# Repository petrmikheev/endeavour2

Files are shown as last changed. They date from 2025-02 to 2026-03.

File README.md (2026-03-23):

Endeavour2
==========

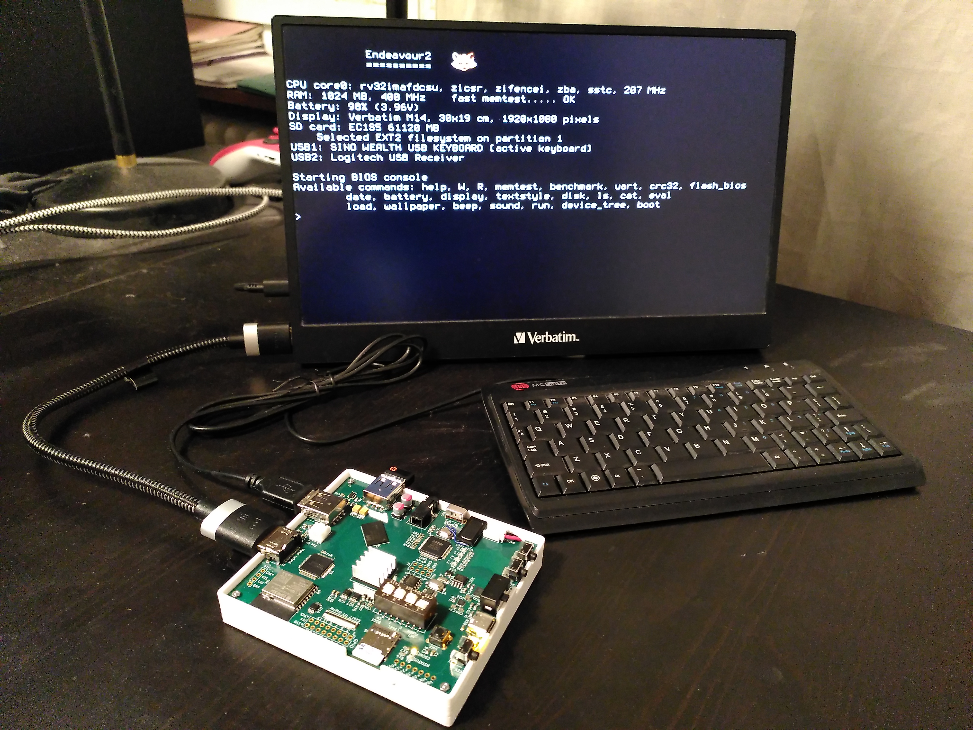
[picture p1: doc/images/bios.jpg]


This is the second generation of my FPGA board.
Comparing to [endeavour1](https://github.com/petrmikheev/endeavour) it is 4 times faster and has 8x more memory.

The goal was the same as on the previous iteration -- to make a DIY computer based on FPGA. It should support display, keyboard, should be able to run Linux, should have on-device compiler toolchain, and ideally should be able to render some 3D graphic. It was fully achieved -- I have even managed to connect my board to WiFi and play Quake2 in multiplayer.

The project includes several parts:

- Hardware: design PCB and make the board. I ordered PCB manufacturing in JLCPCB, soldering is done manually.
- RTL: design SoC for my FPGA board. It is mostly assembled from open source IP cores, but some components are implemented from scratch.
- Firmware: written from scratch (except of integrated Dhrystone benchmark), includes initialization code, memtest, sbi implemetation, ext2 filesystem support, linux bootloader, built-in console. Provides some API (e.g printf) for software running in M-mode.
- Linux drivers for custom peripherals.
- Custom window manager and TTY implementation.

Note: This is a hobby project created just for fun. It doesn't have much practical use. However, if for some reason somebody wants to make a copy of this FPGA board, please let me know. I might add a bit more documentation.

Here's a story about how I worked on the project: **[https://blog.mikhe.ch/quake2-on-fpga](https://blog.mikhe.ch/quake2-on-fpga)**.

License: GPL-3.0 (except of footprints in hardware/endeavour2.pretty and Dhrystone benchmark in software/bios/dhrystone)

## Hardware

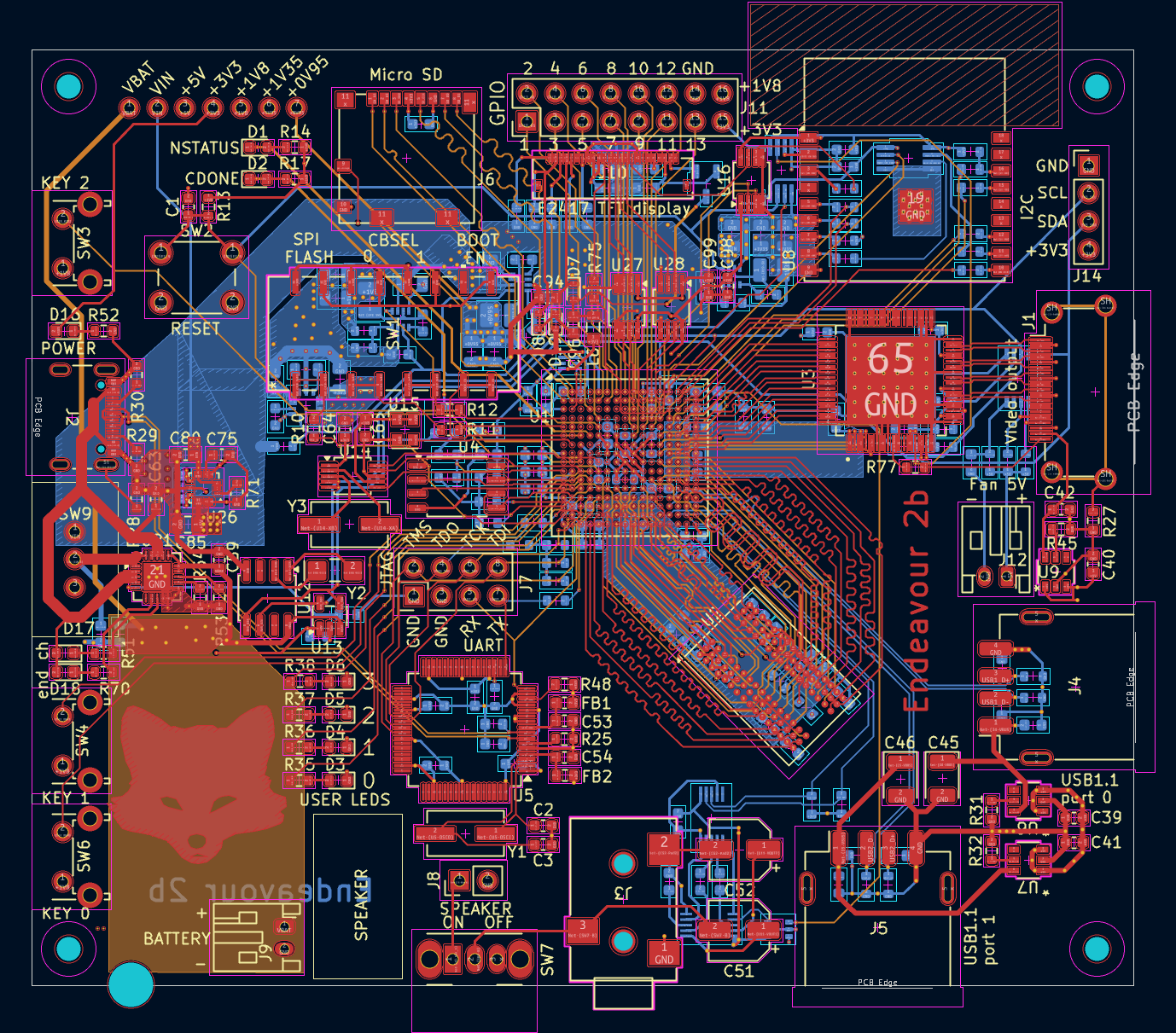
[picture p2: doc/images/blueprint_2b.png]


Main changes comparing to [endeavour1](https://github.com/petrmikheev/endeavour):

- This time I took a chance with BGA (Ball Grid Array) chips, and surprisingly soldering was not as hard as I expected.
- Using Efinix FPGA [Ti60F256](https://www.efinixinc.com/shop/ti60.php) with 60K logic cells and 256 1024x10b memory blocks. VexiiRiscv runs on this chip at frequency 207 MHz -- quite a lot for FPGA, especially in comparison to 60 MHz which I previously got with Altera Max10.
- 1GB DDR3 RAM IM8G16D3FFBG (against 128MB DDR1 in endeavour1). I use Efinix DDR3 Soft Controller Core. Using DDR3-400 mode, 800 MT/s, max theoretical throughput 1.6 GB/s. In practice in benchmarks I get up to 1.1 GB/s.
- Implemented SD Card voltage switch 3.3V/1.8V. In theory it allows to use UHS-1 cards in SDR104 mode (up to 100 MB/s), but for some cards writes failed at this speed, so I use SDR50 (46 MB/s in benchmark).
- Added a specialized TMDS encoder TFP410 (in endeavour1 video output was driven directly by FPGA pins which provided not enough current and caused green artifacts in some cases). Now all display modes with pixel rate up to 165 MHz are supported.
- More capacitors and a current limiting scheme on USB ports. USB hotplug can not cause device reset anymore!
- Added a real time clock in order not to appear in 1970 every time I start linux.
- Added ESP32 module as a WiFi adapter. `wget` shows download speed 926 KB/s.
- Added 2000mAh LiPo battery. 
- Added 4.2'' E-Ink display.

[KiCad project](hardware/board_2b), [gerber files](hardware/board_2b/production/endeavour2.zip).

**PCB production details ([JLCPCB](https://jlcpcb.com/capabilities/pcb-capabilities))**

- 6 layers
- Stackup: JLC06161H-3313
- Min via hole/diameter: 0.2/0.35mm
- Via covering: epoxy filled & capped

---



Endeavour2a (above) and Endeavour2b (below).

### Known design errors

In Endeavour2a:

- D+ and D- lines on USB-C port A are accidentally swapped, so port A can be used only as a power source. There are two USB-C ports because I was not sure that USB connection to PC will give enough power, and added a second USB-C for a power adapter. It turned out to be unnecessary, so in Endeavour2b the second port is removed.
- ESP32 connection scheme includes not all the pins which are needed for [ESP-Hosted-NG](https://github.com/espressif/esp-hosted/blob/master/esp_hosted_ng/README.md) firmware. I tried to remap some pins, but it caused extra delays and SPI transfers didn't work properly. So Endeavour2a has no WiFi. Fixed in Endeavour2b.

In Endeavour2b:

- Using same DC-DC converters as in Endeavour2a (TPS562211) to generate 0.95V, 1.35V, 1.8V. I forgot that it requires input power at least 4.2V and can work from USB (which was the case in Endeavour2a), but not from a battery pack. So the device can use battery power only when the battery is fully charged. Will be fixed in Endeavour2c.

### 3d printed case

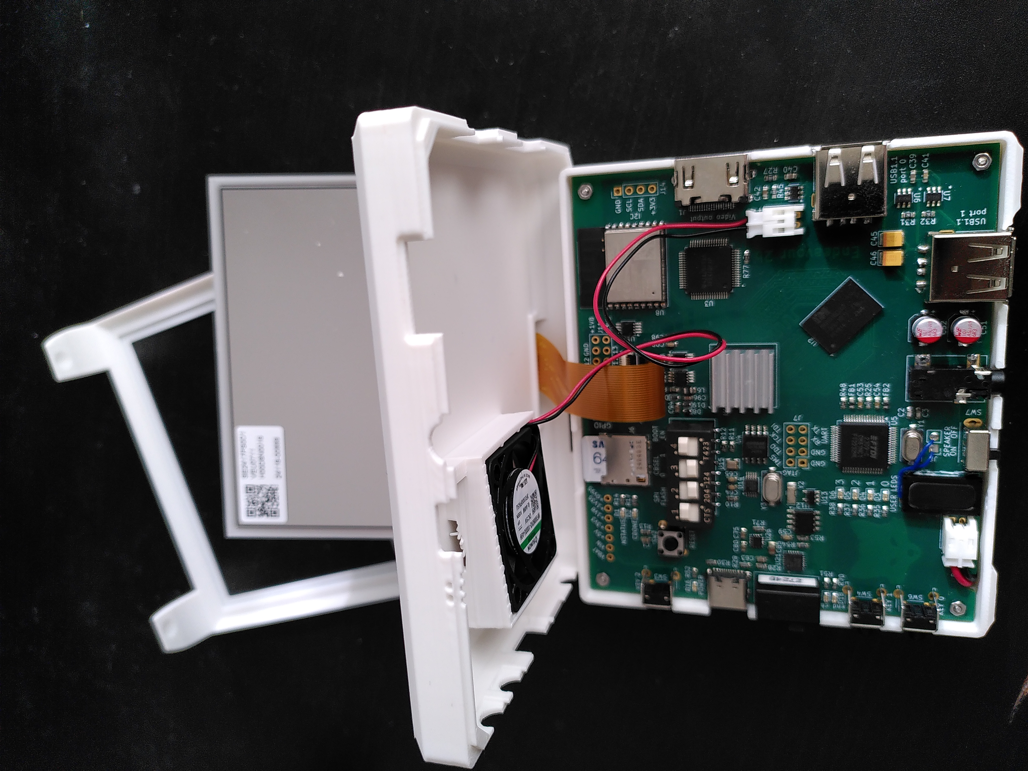
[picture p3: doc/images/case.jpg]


---



## RTL

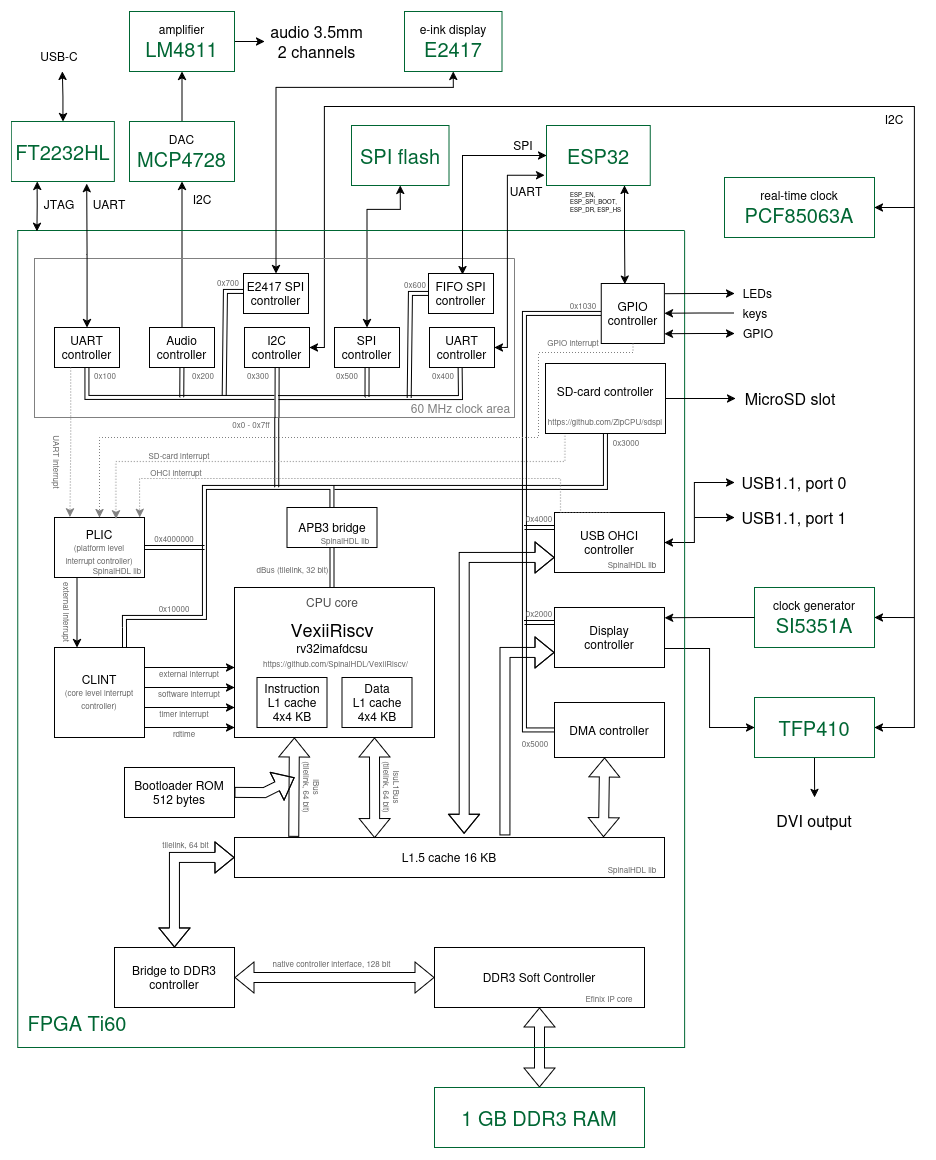
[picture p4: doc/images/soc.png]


Used IP cores:

- [VexiiRiscv](https://github.com/SpinalHDL/VexiiRiscv/) - RISC-V core written in SpinalHDL.
- A few components distributed with [SpinalHDL](https://github.com/SpinalHDL/SpinalHDL) including Tilelink interconnect, APB3 bridge, USB OHCI controller, PLIC.
- [ZipCPU/sdspi SD-Card controller](https://github.com/ZipCPU/sdspi).
- [Efinix DDR3 Soft Controller Core](https://www.efinixinc.com/support/ip/ddr3-controller.php) (source not available, can be used only with Efinix FPGAs).

All the other components are designed from scratch.
DDR3 Tilelink adapter, UART controller, I2C controller, audio controller, SPI controllers (SPI FLASH, ESP32 SPI, and E2417 SPI interfaces have different requirements, so I end up with 3 different SPI controllers optimized for specific use cases), etc. Most notable are video controller and DMA controller.

[SpinalHDL](https://github.com/SpinalHDL/SpinalHDL) is being used to bring this all together.

### Video controller

- Has idependent text and graphic layers with transparency support.
- Configurable video timings.
- Supports both vertical (with wraparound) and horizontal panning.
- Graphic layer uses RGB565 format.
- Text layer has configurable charmap with 480 entries - e.g. ASCII + bold + italic variations + pseudographics can be loaded at the same time. Supports bitmap fonts with sizes from 8x8 to 8x16. Supports special 4-color symbols mode (used to render Endeavour logo, see screenshots below).
- APB3 control interface, Tilelink DMA interface.
- Implemented in verilog. [source](rtl/verilog/video_controller.v)
- There is [linux driver](software/linux/drivers/display.c). See usage in [include/endeavour2/display.h](software/include/endeavour2/display.h).

### DMA controller

- Can execute multiple memory operations by a single batch request from CPU (needed e.g. for hardware-accelerated window move in X11 since each line requires separate copying).
- Supports unaligned memset and memcpy (also essential for window move).
- Supports some graphics-related instructions: batched RGB565 mixing and palette mapping. So it is kind of a very primitive 2D GPU. I used it to speedup rendering in Quake2.
- APB3 control interface, Tilelink DMA interface.
- Implemented in SpinalHDL. [source](rtl/src/main/scala/endeavour2/DmaController.scala)

## Software

### [software/bios](software/bios)

Firmware. Initialization, benchmarks, sbi, bootloader, etc. Loaded on boot from SPI flash or via UART.

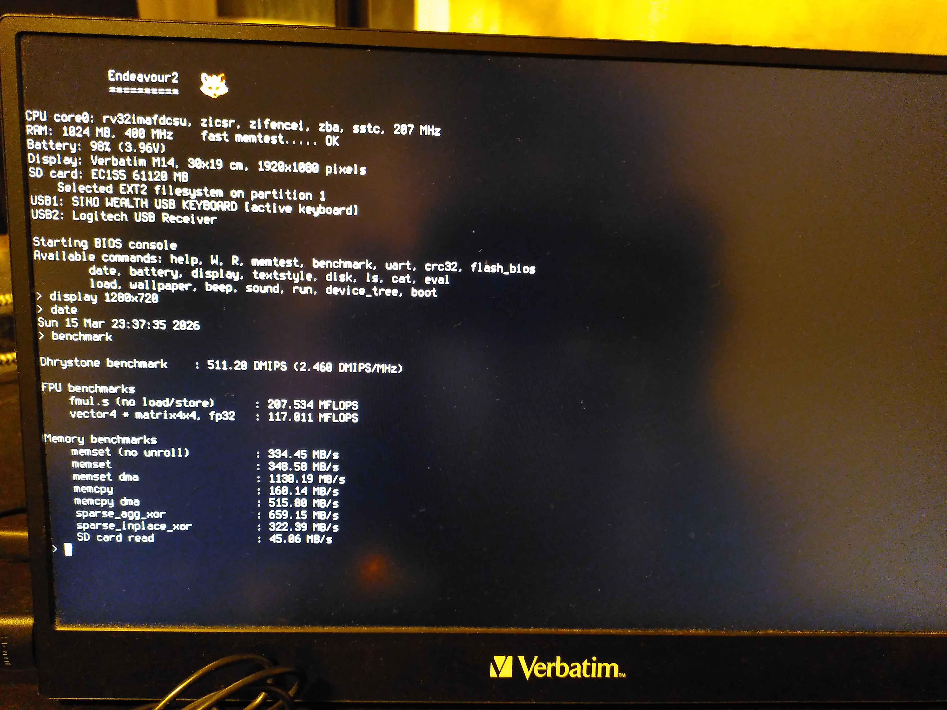
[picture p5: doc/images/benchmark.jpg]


BIOS console allows to either boot OS (switches to supervisor mode), or inspect files (only EXT2 supported) and run binaries in machine mode.

BIOS provides API: [bios.h](software/include/endeavour2/raw/bios.h)

Example that uses this API: [hello_world.c](software/raw_examples/hello_world.c)

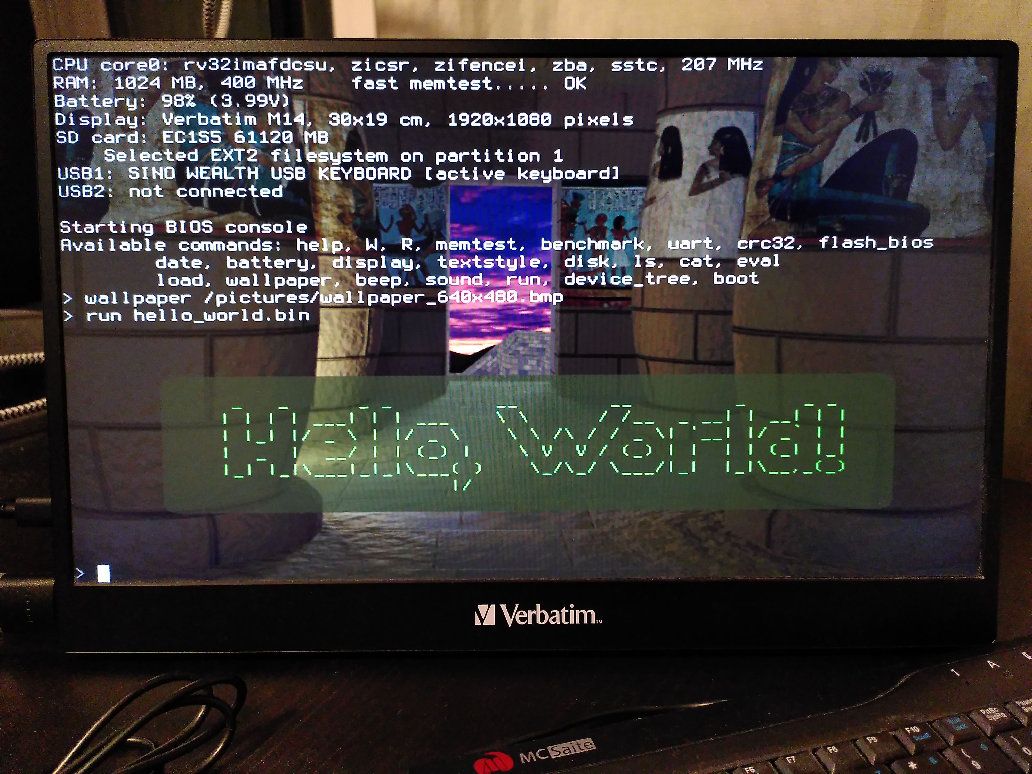
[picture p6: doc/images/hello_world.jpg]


### [software/textwm2](software/textwm2)

Text-layer window manager and TTY implementation.

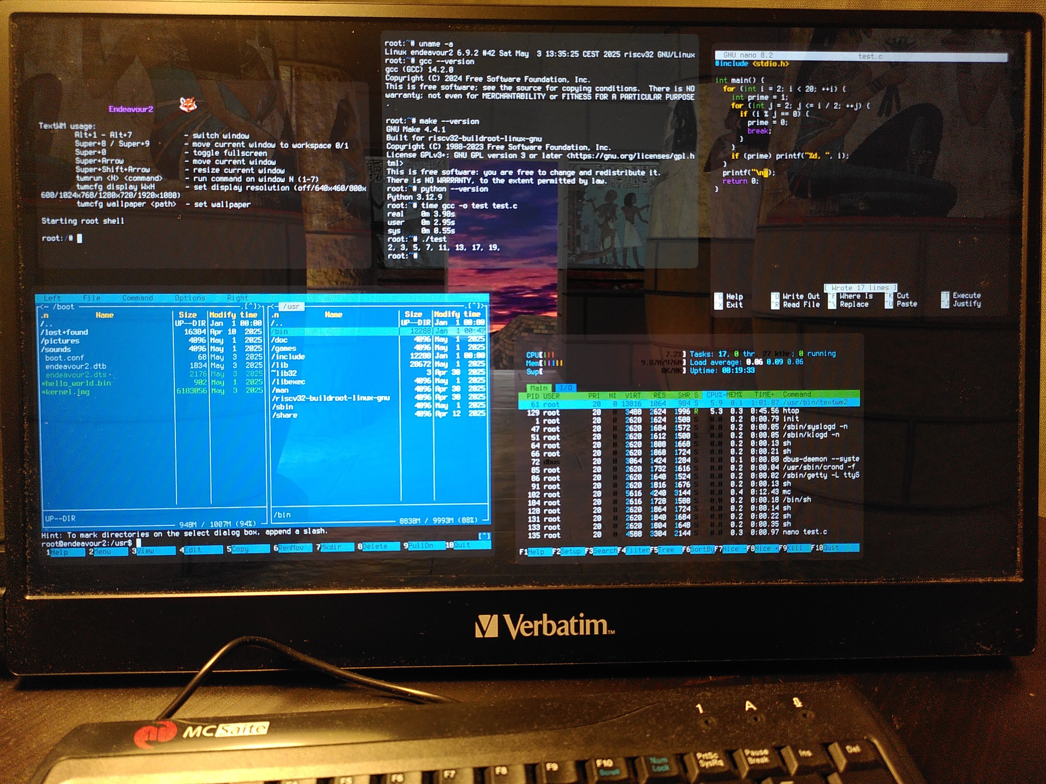
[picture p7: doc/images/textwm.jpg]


---

**wget 926 KB/s**, ESP32 as WiFi/BT adapter.



### [software/linux](software/linux)

Linux kernel config and drivers.

### [software/buildroot](software/buildroot)

Buildroot config and a few related scripts.

### [xdriver-endeavour2-fbdev](software/buildroot/xdriver-endeavour2-fbdev)

X11 driver which uses DMA controller when moving windows.

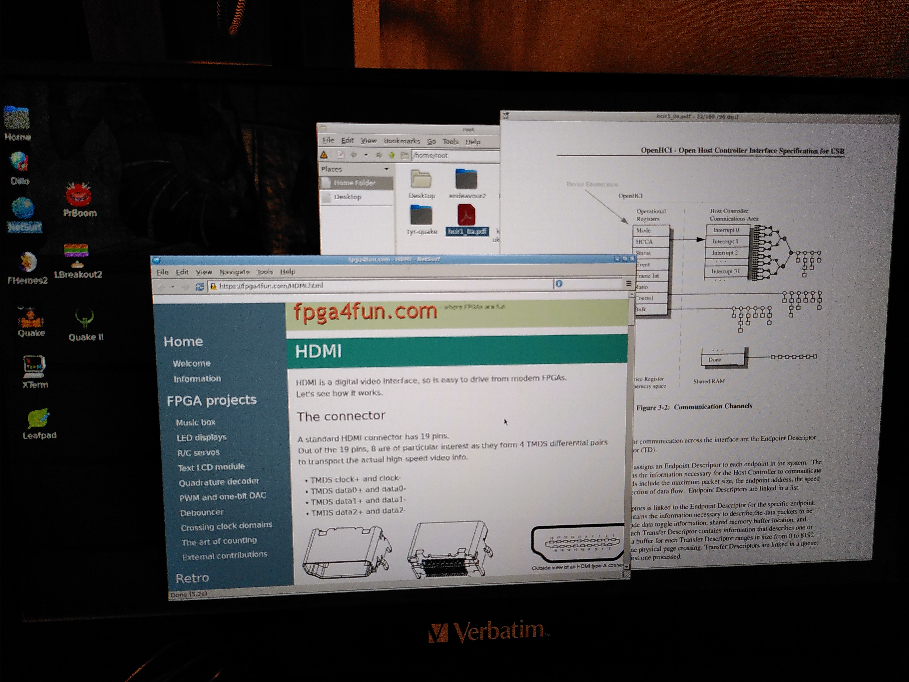
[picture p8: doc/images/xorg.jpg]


### [quake2sdl.patch](software/buildroot/quake2sdl.patch)



Patch for [quake2sdl](https://github.com/shamazmazum/quake2sdl).

- Using DMA controller for hardware-accelerated mapping from 256 colors to RGB565, and bilinear upscaling.
- Migrated from SDL audio to a custom endeavour2 driver with lower overhead (overhead of ALSA subsystem was quite significant).
- Downgraded from SDL2 to SDL1 (so it can run without X11).

Average FPS 12.2 on demo1 map with resolution 640x360 and bilinear upscaling to 1280x720.

### A few more screenshots

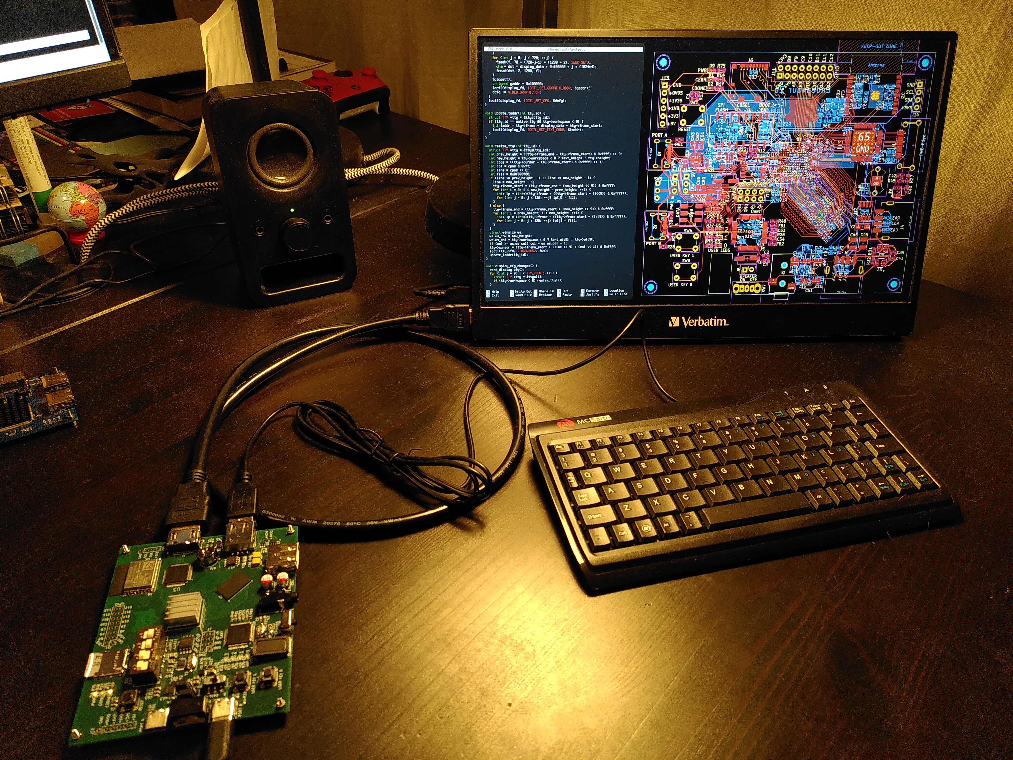
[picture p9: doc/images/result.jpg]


---

**DOOM**

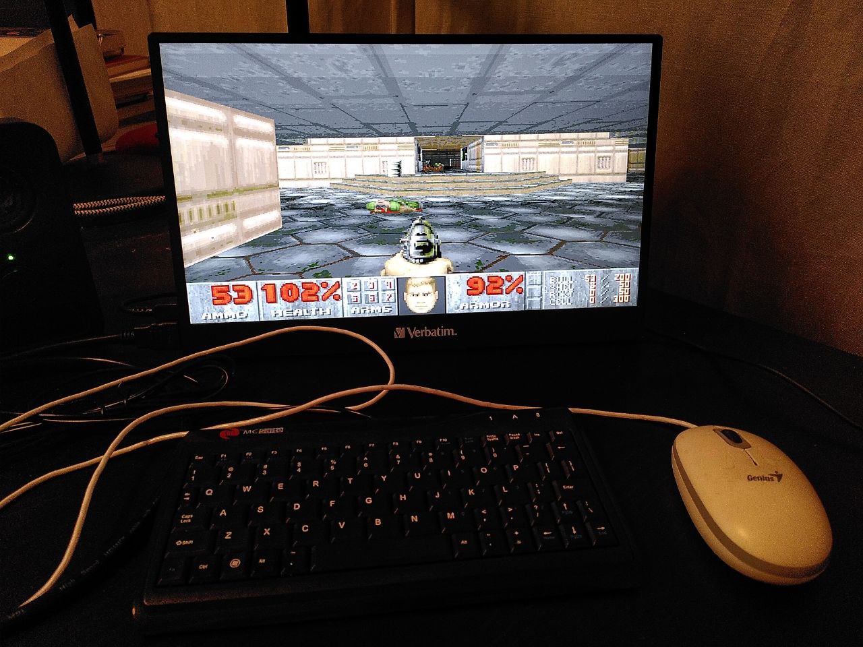
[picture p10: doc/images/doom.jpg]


---

**Quake 1**



---

**Heroes2**

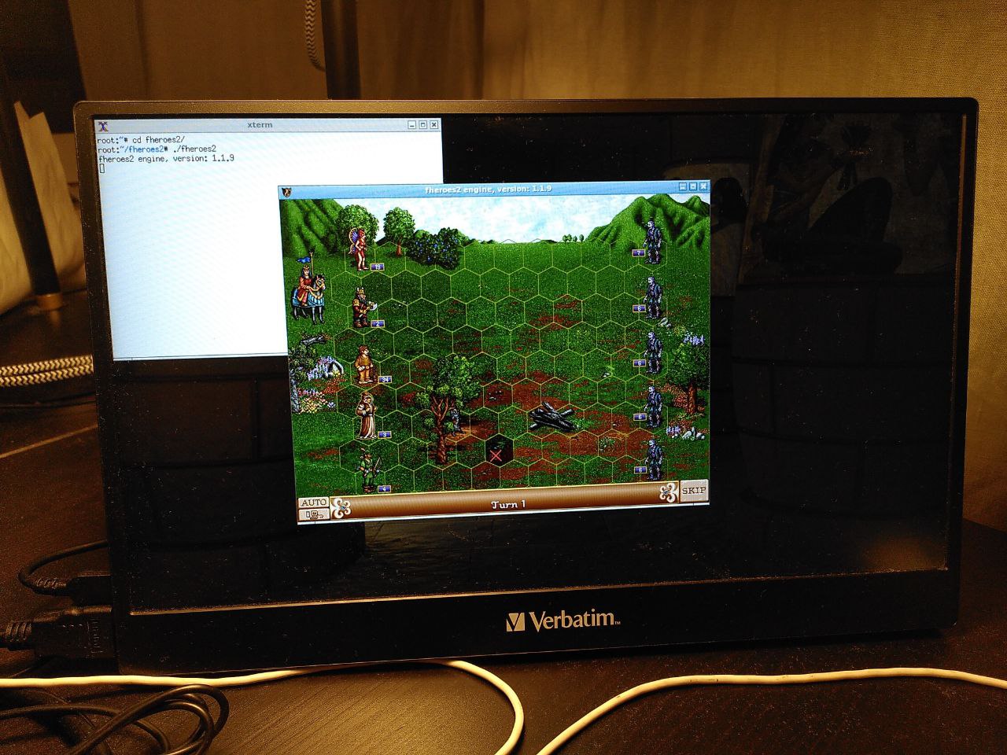
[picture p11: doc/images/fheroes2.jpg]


---

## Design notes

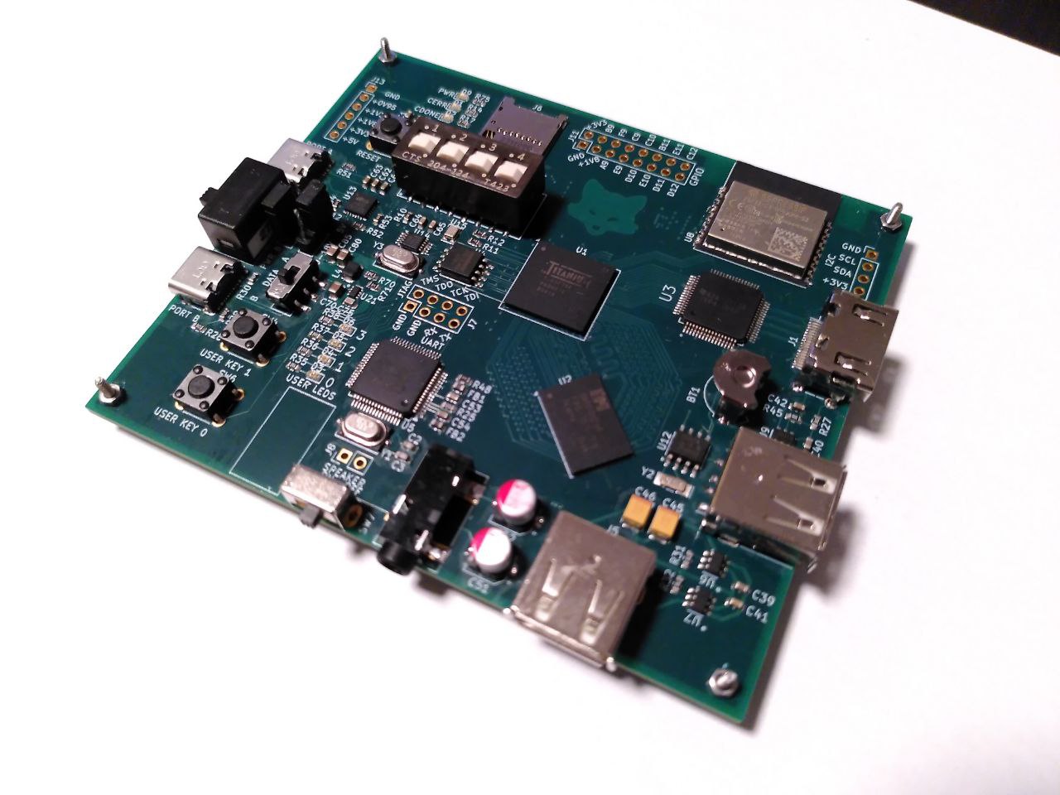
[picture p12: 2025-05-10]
doc/images/board_2a.jpg

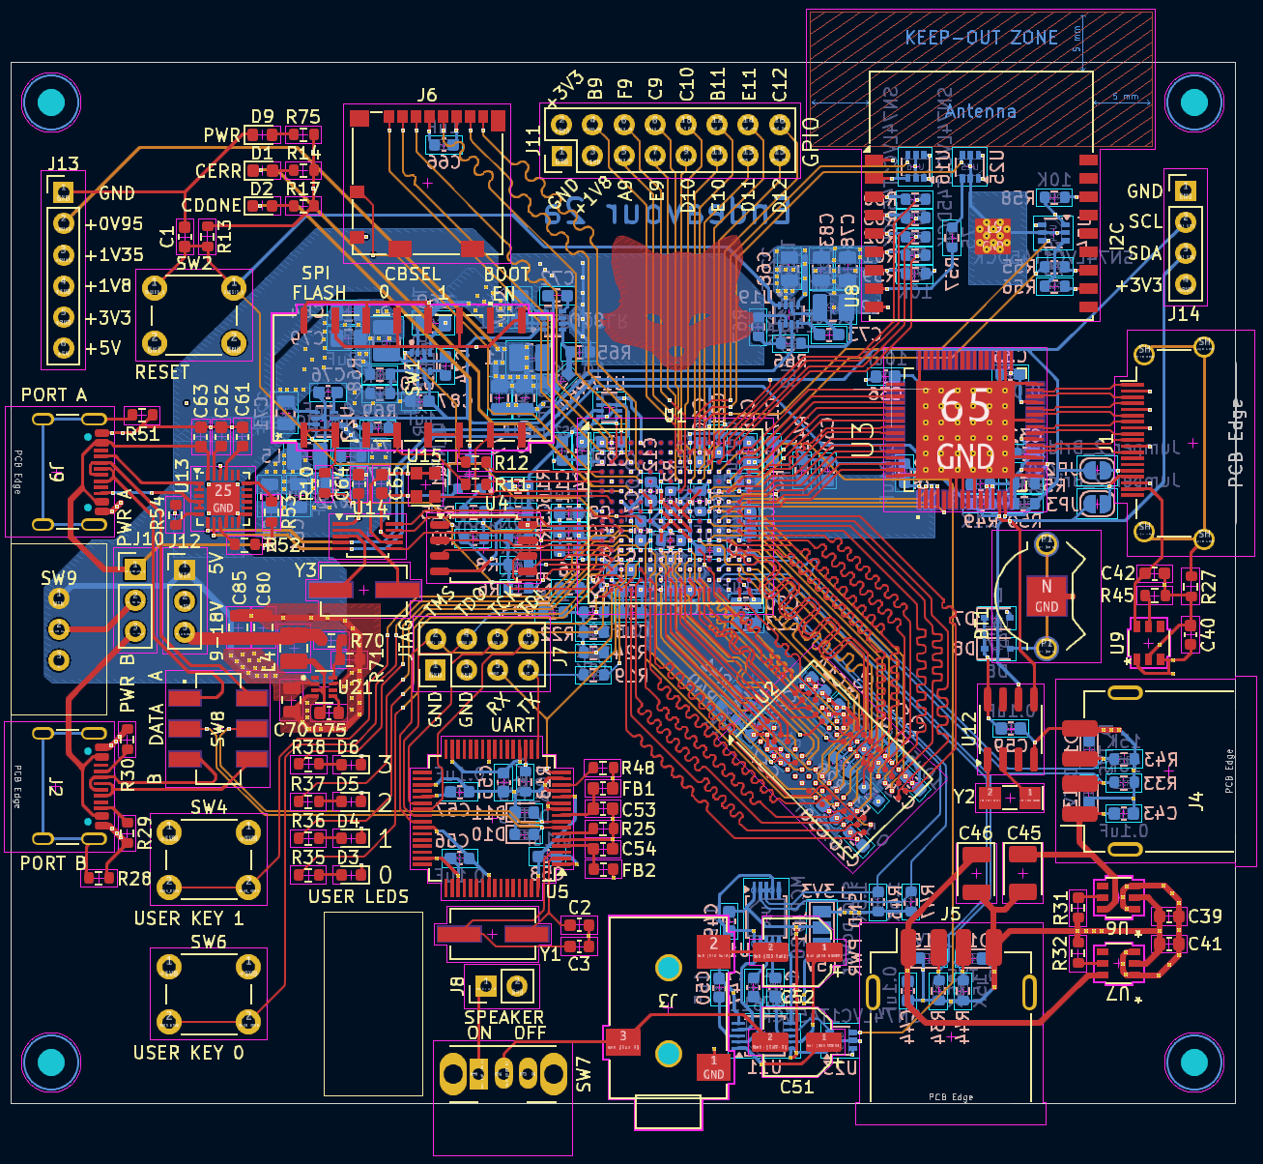
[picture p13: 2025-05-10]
doc/images/blueprint_2a.png

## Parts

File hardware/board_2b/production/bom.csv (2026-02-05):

Designator | Footprint | Quantity | Value | LCSC Part #
 |  | 1
C1, C14, C17, C4, C47, C48, C49, C50, C53, C54, C66, C75, C76, C87, C9, C91 | 0603 | 16 | 1uF
C10, C13, C24, C36, C39, C40, C42, C63, C71, C80 | 0603 | 10 | 10uF
C100, C101, C19, C20, C21, C22, C25, C26, C29, C30, C31, C41, C43, C44, C5, C55, C56, C57, C58, C59, C60, C64, C65, C70, C72, C73, C74, C93, C97, C98, C99 | 0603 | 31 | 0.1uF
C11, C23, C28, C61, C62, C8, C86, C88, C89, C90, C92, C94, C95, C96 | 0603 | 14 | 4.7uF
C12, C15, C18, C27, C32, C33, C34, C35, C37, C38, C7 | 0603 | 11 | 0.01uF
C16, C6 | 0603 | 2 | 47uF
C2, C3 | 0603 | 2 | 27pF
C45, C46 | CP_EIA-3528-12_Kemet-T | 2 | 100uF
C51, C52 | CP_Elec_5x5.3 | 2 | 100uF
C67, C68, C69, C77, C78, C79, C81, C82, C83, C84, C85 | 0805 | 11 | 22uF
D1, D17 | 0603 | 2 | 5988E20107F
D10, D11, D12, D13, D14, D15 | 0603 | 6 | D_TVS 3v3
D16, D18, D2, D3, D4, D5, D6 | 0603 | 7 | 5988E40107F
D19, D7, D8 | D_SOD-523 | 3 | RB751S40T1G
FB1, FB2 | 0603 | 2 | 120
J1 | HDMI_A_Amphenol_10029449-x01xLF_Horizontal | 1 | HDMI_A
J10 | CONN24X1_CF35242D0RE-NH_CVI | 1 | CF35242D0RE-NH
J11 | PinHeader_2x08_P2.54mm_Vertical | 1 | Conn_GPIO
J12 | JST_PH_S2B-PH-K_1x02_P2.00mm_Horizontal | 1 | Fan
J13 | PinHeader_1x07_P2.54mm_Vertical | 1 | power_test_points
J14 | PinHeader_1x04_P2.54mm_Vertical | 1 | Conn_01x04_Pin
J2 | USB_C_Receptacle_GCT_USB4105-xx-A_16P_TopMnt_Horizontal | 1 | USB_C_Receptacle_USB2.0
J3 | SJ-3523-SMT_CUD | 1 | SJ-3523-SMT
J4, J5 | USB_A_Receptacle_GCT_USB1046 | 2 | USB_A
J6 | microSD_HC_Molex_104031-0811 | 1 | Micro_SD_Card_Det2
J7 | PinHeader_2x04_P2.54mm_Vertical | 1 | Conn_02x04_Odd_Even
J8 | PinHeader_1x02_P2.54mm_Vertical | 1 | Conn_01x02
J9 | JST_PH_S2B-PH-K_1x02_P2.00mm_Horizontal | 1 | Battery
L1, L2, L3 | 1008 | 3 | 2.2uH
L4, L5 | 0805 | 2 | 1uH
L6 | 0805 | 1 | 10uH
Q1 | SC-59 | 1 | Q_NPN_BEC 2SC3326-B,LF
Q2 | SOT-23-3 | 1 | SSM3K336R,LF
R1 | 0603 | 1 | 240
R10, R11, R12, R13, R16, R18, R2, R21, R22, R23, R24, R3, R4, R58, R59, R6, R7, R74, R8, R9, TH1 | 0603 | 21 | 10K
R14, R17, R35, R36, R37, R38 | 0603 | 6 | 25
R15 | 0603 | 1 | 100K
R19, R20, R55, R56, R57, R60, R61, R62, R63, R73, R75, R76 | 0603 | 12 | 75
R25 | 0603 | 1 | 12K
R26 | 0603 | 1 | 100
R27, R28 | 0603 | 2 | 1M
R29, R30, R49, R50 | 0603 | 4 | 5.1K
R31, R32 | 0603 | 2 | 60K
R33, R34, R43, R44, R54 | 0603 | 5 | 15K
R39, R40, R41, R42, R48, R77 | 0603 | 6 | 1K
R45, R78 | 0603 | 2 | 200K
R46, R47 | 0603 | 2 | 1.5K
R5, R52 | 0603 | 2 | 510
R51, R70 | 0603 | 2 | 560
R53, R79, R80 | 0603 | 3 | 2K
R64 | 0603 | 1 | 23.2K
R65, R68 | 0603 | 2 | 40.2K
R66 | 0603 | 1 | 24.9K
R67, R69 | 0603 | 2 | 20K
R71 | 0603 | 1 | 4.99K
R72 | 0603 | 1 | 0.47
SW1 | SPDT_204-124_CTS | 1 | 204-124ST
SW2 | SW_PUSH_6mm | 1 | SW_Push TS02
SW3, SW4, SW6 | SW_Tactile_SPST_Angled_PTS645Vx58-2LFS | 3 | SW_Push TS11
SW7 | SW_Slide_SPDT_Angled_CK_OS102011MA1Q | 1 | SW_SPDT SLW-864587-2A-RA-N-D
SW9 | mss3111 | 1 | MSS 3111 D-R
U1 | BGA-256_14.0x14.0mm_Layout16x16_P0.8mm_Ball0.45mm_Pad0.32mm_NSMD | 1 | Ti60F256
U10 | MSOP-10_3x3mm_P0.5mm | 1 | MCP4728
U11 | TSSOP-10_3x3mm_P0.5mm | 1 | LM4811
U12 | SOIC-8_3.9x4.9mm_P1.27mm | 1 | PCF85063AT
U13 | SOT-23-5 | 1 | MCP3221/MCP3021
U14 | MSOP-10_3x3mm_P0.5mm | 1 | Si5351A-B-GT
U15 | Oscillator_SMD_Kyocera_KC2520Z-4Pin_2.5x2.0mm | 1 | MC2520Z 25MHz
U16, U24, U27, U28, U31 | MSOP-8_3x3mm_P0.65mm | 5 | SN74LVC2T45DCTR
U17 | SOTFL50P160X60-8N | 1 | TPS2116DRLR
U18, U19, U20 | DRL0008A-MFG | 3 | TPS562211DRLR
U2 | BGA-96_9.0x13.5mm_Layout2x3x16_P0.8mm | 1 | IM8G16D3FFBG
U21 | QFN-20-1EP_4x4mm_P0.5mm_EP2.5x2.5mm | 1 | MCP73871-2CC
U22, U26 | Maxim_FC2QFN-14_2.5x2.5mm_P0.5mm | 2 | MAX77827AEFD
U23 | SOT-363_SC-70-6 | 1 | SN74LVC1T45DCK
U25 | TSSOP-8_3x3mm_P0.65mm | 1 | PCA9306DP
U3 | IC_TFP410PAP | 1 | TFP410PAP
U4 | SOIC-8_5.23x5.23mm_P1.27mm | 1 | W25Q128JWS
U5 | LQFP-64_10x10mm_P0.5mm | 1 | FT2232HL
U6, U7, U9 | SOT26_DIO | 3 | AP22653W6-7
U8 | ESP32-C3-WROOM-02 | 1 | ESP32-C3-WROOM-02-N4
Y1 | XTAL_ECS-120-20-3X-TR | 1 | ECS120-20-3XTR 12MHz
Y2 | Crystal_SMD_MicroCrystal_CC7V-T1A-2Pin_3.2x1.5mm_HandSoldering | 1 | CM315D32768HZFT
Y3 | XTAL_ECS-120-20-3X-TR | 1 | ECS250-20-3XTR 25MHz

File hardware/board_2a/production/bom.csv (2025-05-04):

Designator | Footprint | Quantity | Value | LCSC Part #
BT1 | BAT_2989 | 1 | Battery_Cell
C1, C14, C17, C4, C47, C48, C49, C50, C53, C54, C61, C62, C63, C66, C87, C9 | 0603 | 16 | 1uF
C10, C13, C24, C36, C39, C40, C42 | 0603 | 7 | 10uF
C11, C23, C28, C8 | 0603 | 4 | 4.7uF
C12, C15, C18, C27, C32, C33, C34, C35, C37, C38, C7 | 0603 | 11 | 0.01uF
C16, C6 | 0603 | 2 | 47uF
C19, C20, C21, C22, C25, C26, C29, C30, C31, C41, C43, C44, C5, C55, C56, C57, C58, C59, C60, C64, C65, C72, C73, C74, C75, C76 | 0603 | 26 | 0.1uF
C2, C3 | 0603 | 2 | 27pF
C45, C46 | CP_EIA-3528-12_Kemet-T | 2 | 100uF
C51, C52 | CP_Elec_5x5.3 | 2 | 100uF
C67, C68, C69, C70, C71, C77, C78, C79, C80, C81, C82, C83, C84, C85, C86 | 0805 | 15 | 22uF
D1, D2, D3, D4, D5, D6, D9 | 0603 | 7 | LED
D10, D11, D12, D13, D14, D15 | 0603 | 6 | D_TVS
D7, D8 | D_SOD-323 | 2 | D
FB1, FB2 | 0603 | 2 | ~
J1 | HDMI_A_Amphenol_10029449-x01xLF_Horizontal | 1 | HDMI_A
J10 | PinHeader_1x03_P2.54mm_Vertical | 1 | jumper_power_source
J11 | PinHeader_2x08_P2.54mm_Vertical | 1 | Conn_GPIO
J12 | PinHeader_1x03_P2.54mm_Vertical | 1 | jumper_5v
J13 | PinHeader_1x06_P2.54mm_Vertical | 1 | Conn_power
J14 | PinHeader_1x04_P2.54mm_Vertical | 1 | Conn_01x04_Pin
J2, J9 | USB_C_Receptacle_GCT_USB4105-xx-A_16P_TopMnt_Horizontal | 2 | USB_C_Receptacle_USB2.0
J3 | SJ-3523-SMT_CUD | 1 | SJ-3523-SMT
J4, J5 | USB_A_Receptacle_GCT_USB1046 | 2 | USB_A
J6 | microSD_HC_Molex_104031-0811 | 1 | Micro_SD_Card_Det2
J7 | PinHeader_2x04_P2.54mm_Vertical | 1 | Conn_02x04_Odd_Even
J8 | PinHeader_1x02_P2.54mm_Vertical | 1 | Conn_01x02
JP1 | SolderJumper-3_P1.3mm_Open_Pad1.0x1.5mm | 1 | snd_power
JP2, JP3 | SolderJumper-2_P1.3mm_Open_RoundedPad1.0x1.5mm | 2 | Jumper_2_Bridged
L1, L2, L3 | 1008 | 3 | 2.2uH
L4, L5 | 1008 | 2 | 4.7uH
Q1 | SC-59 | 1 | Q_NPN_BEC
R1 | 0603 | 1 | 240
R10, R11, R12, R13, R16, R18, R2, R21, R22, R23, R24, R3, R4, R54, R58, R59, R6, R7, R71, R73, R74, R8, R9 | 0603 | 23 | 10K
R14, R17, R35, R36, R37, R38, R75 | 0603 | 7 | 25
R15 | 0603 | 1 | 100K
R19, R20, R55, R56, R57, R60, R61, R62, R63 | 0603 | 9 | 75
R25 | 0603 | 1 | 12K
R26 | 0603 | 1 | 100
R27, R28, R51 | 0603 | 3 | 1M
R29, R30, R49, R50 | 0603 | 4 | 5.1K
R31, R32 | 0603 | 2 | 60K
R33, R34, R43, R44 | 0603 | 4 | 15K
R39, R40, R41, R42, R48, R52, R53 | 0603 | 7 | 1K
R45 | 0603 | 1 | 200K
R46, R47 | 0603 | 2 | 1.5K
R5 | 0603 | 1 | 510
R64 | 0603 | 1 | 23.2K
R65, R68 | 0603 | 2 | 40.2K
R66 | 0603 | 1 | 24.9K
R67, R69 | 0603 | 2 | 20K
R70 | 0603 | 1 | 73.2K
R72 | 0603 | 1 | 45.3K
SW1 | SPDT_204-124_CTS | 1 | 204-124ST
SW2, SW4, SW6 | SW_PUSH_6mm | 3 | SW_Push
SW7 | SW_Slide_SPDT_Angled_CK_OS102011MA1Q | 1 | SW_SPDT
SW8 | SW_JS202011SCQN | 1 | ~
SW9 | mss3111 | 1 | SW_SPDT
U1 | BGA-256_14.0x14.0mm_Layout16x16_P0.8mm_Ball0.45mm_Pad0.32mm_NSMD | 1 | Ti60F256
U10 | MSOP-10_3x3mm_P0.5mm | 1 | MCP4728
U11 | TSSOP-10_3x3mm_P0.5mm | 1 | LM4811
U12 | SOIC-8_3.9x4.9mm_P1.27mm | 1 | PCF85063AT/AY
U13 | QFN-24-1EP_4x4mm_P0.5mm_EP2.7x2.7mm | 1 | STUSB4500QTR
U14 | MSOP-10_3x3mm_P0.5mm | 1 | Si5351A-B-GT
U15 | Oscillator_SMD_Kyocera_KC2520Z-4Pin_2.5x2.0mm | 1 | MC2520Z 25MHz
U16, U23, U24, U25 | SOT-363_SC-70-6 | 4 | SN74LVC1T45DCK
U17 | SOTFL50P160X60-8N | 1 | TPS2116DRLR
U18, U19, U20, U21, U22 | DRL0008A-MFG | 5 | TPS562211DRLR
U2 | BGA-96_9.0x13.5mm_Layout2x3x16_P0.8mm | 1 | IM8G16D3FFBG
U3 | IC_TFP410PAP | 1 | TFP410PAP
U4 | SOIC-8_5.23x5.23mm_P1.27mm | 1 | W25Q128JWS
U5 | LQFP-64_10x10mm_P0.5mm | 1 | FT2232HL
U6, U7, U9 | SOT26_DIO | 3 | AP22653W6-7
U8 | ESP32-C3-WROOM-02 | 1 | ESP32-C3-WROOM-02-N4
Y1 | XTAL_ECS-120-20-3X-TR | 1 | 12MHz
Y2 | Crystal_SMD_MicroCrystal_CC7V-T1A-2Pin_3.2x1.5mm_HandSoldering | 1 | Crystal
Y3 | XTAL_ECS-120-20-3X-TR | 1 | 25MHz

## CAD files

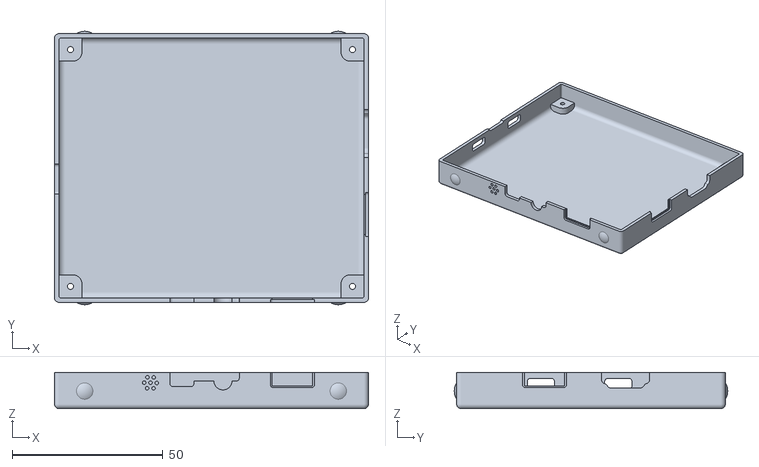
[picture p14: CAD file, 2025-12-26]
hardware/board_2a/case_bottom.stl
104.0 x 90.6 x 12.0

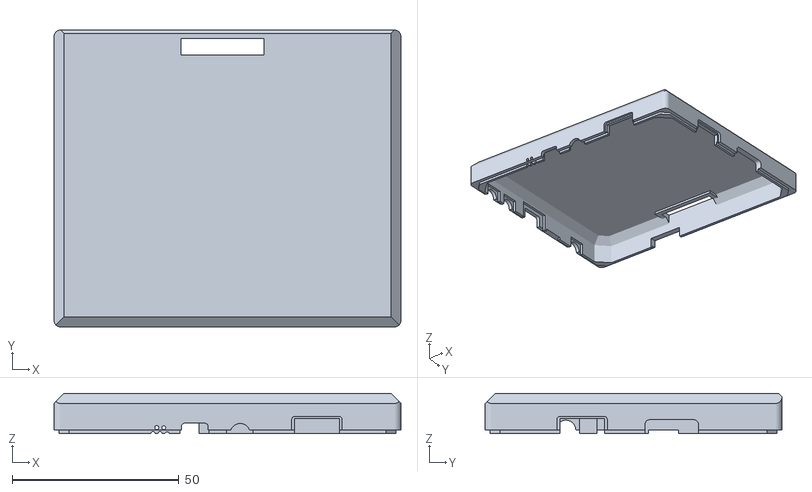
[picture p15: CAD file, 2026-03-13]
hardware/board_2b/case_middle.stl
104.0 x 89.0 x 12.0

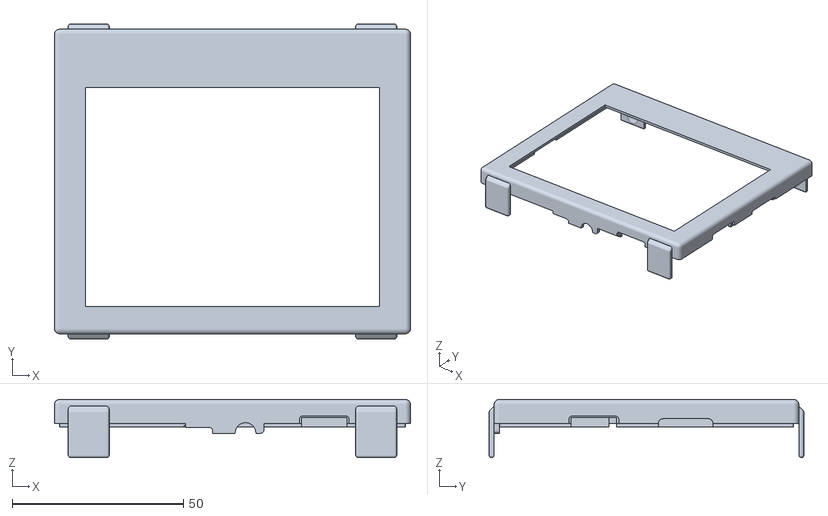
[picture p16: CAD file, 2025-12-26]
hardware/board_2a/case_top.stl
104.0 x 92.0 x 17.0

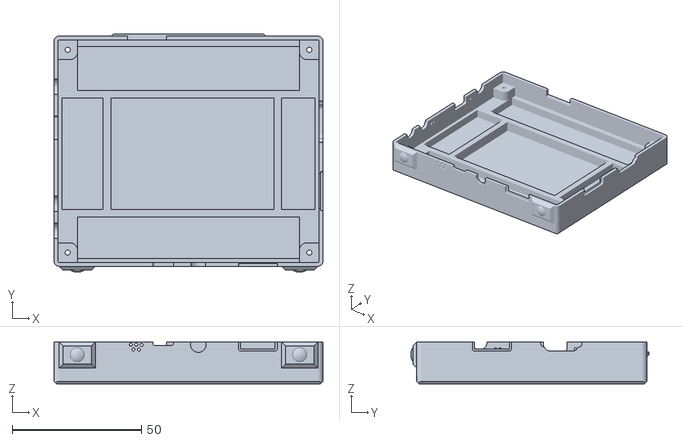
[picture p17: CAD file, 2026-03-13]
hardware/board_2b/case_bottom.stl
104.0 x 92.2 x 16.2

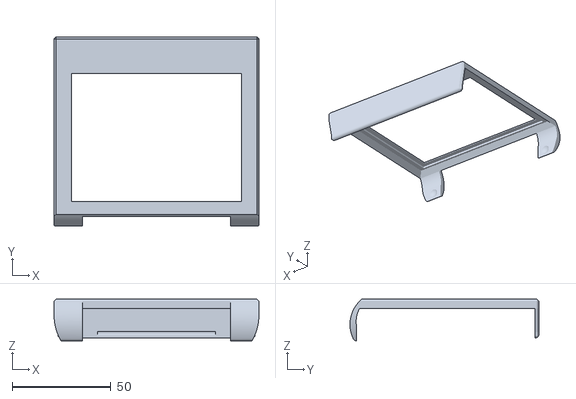
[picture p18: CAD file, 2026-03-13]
hardware/board_2b/case_top.stl
104.0 x 95.9 x 21.2

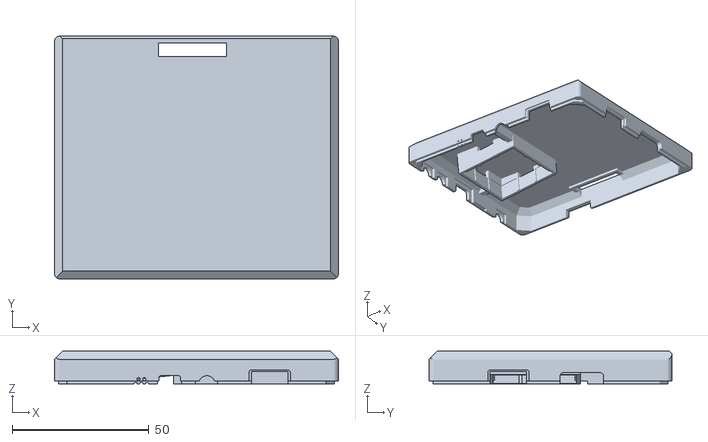
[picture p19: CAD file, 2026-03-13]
hardware/board_2b/case_middle_f.stl
104.0 x 89.0 x 12.0

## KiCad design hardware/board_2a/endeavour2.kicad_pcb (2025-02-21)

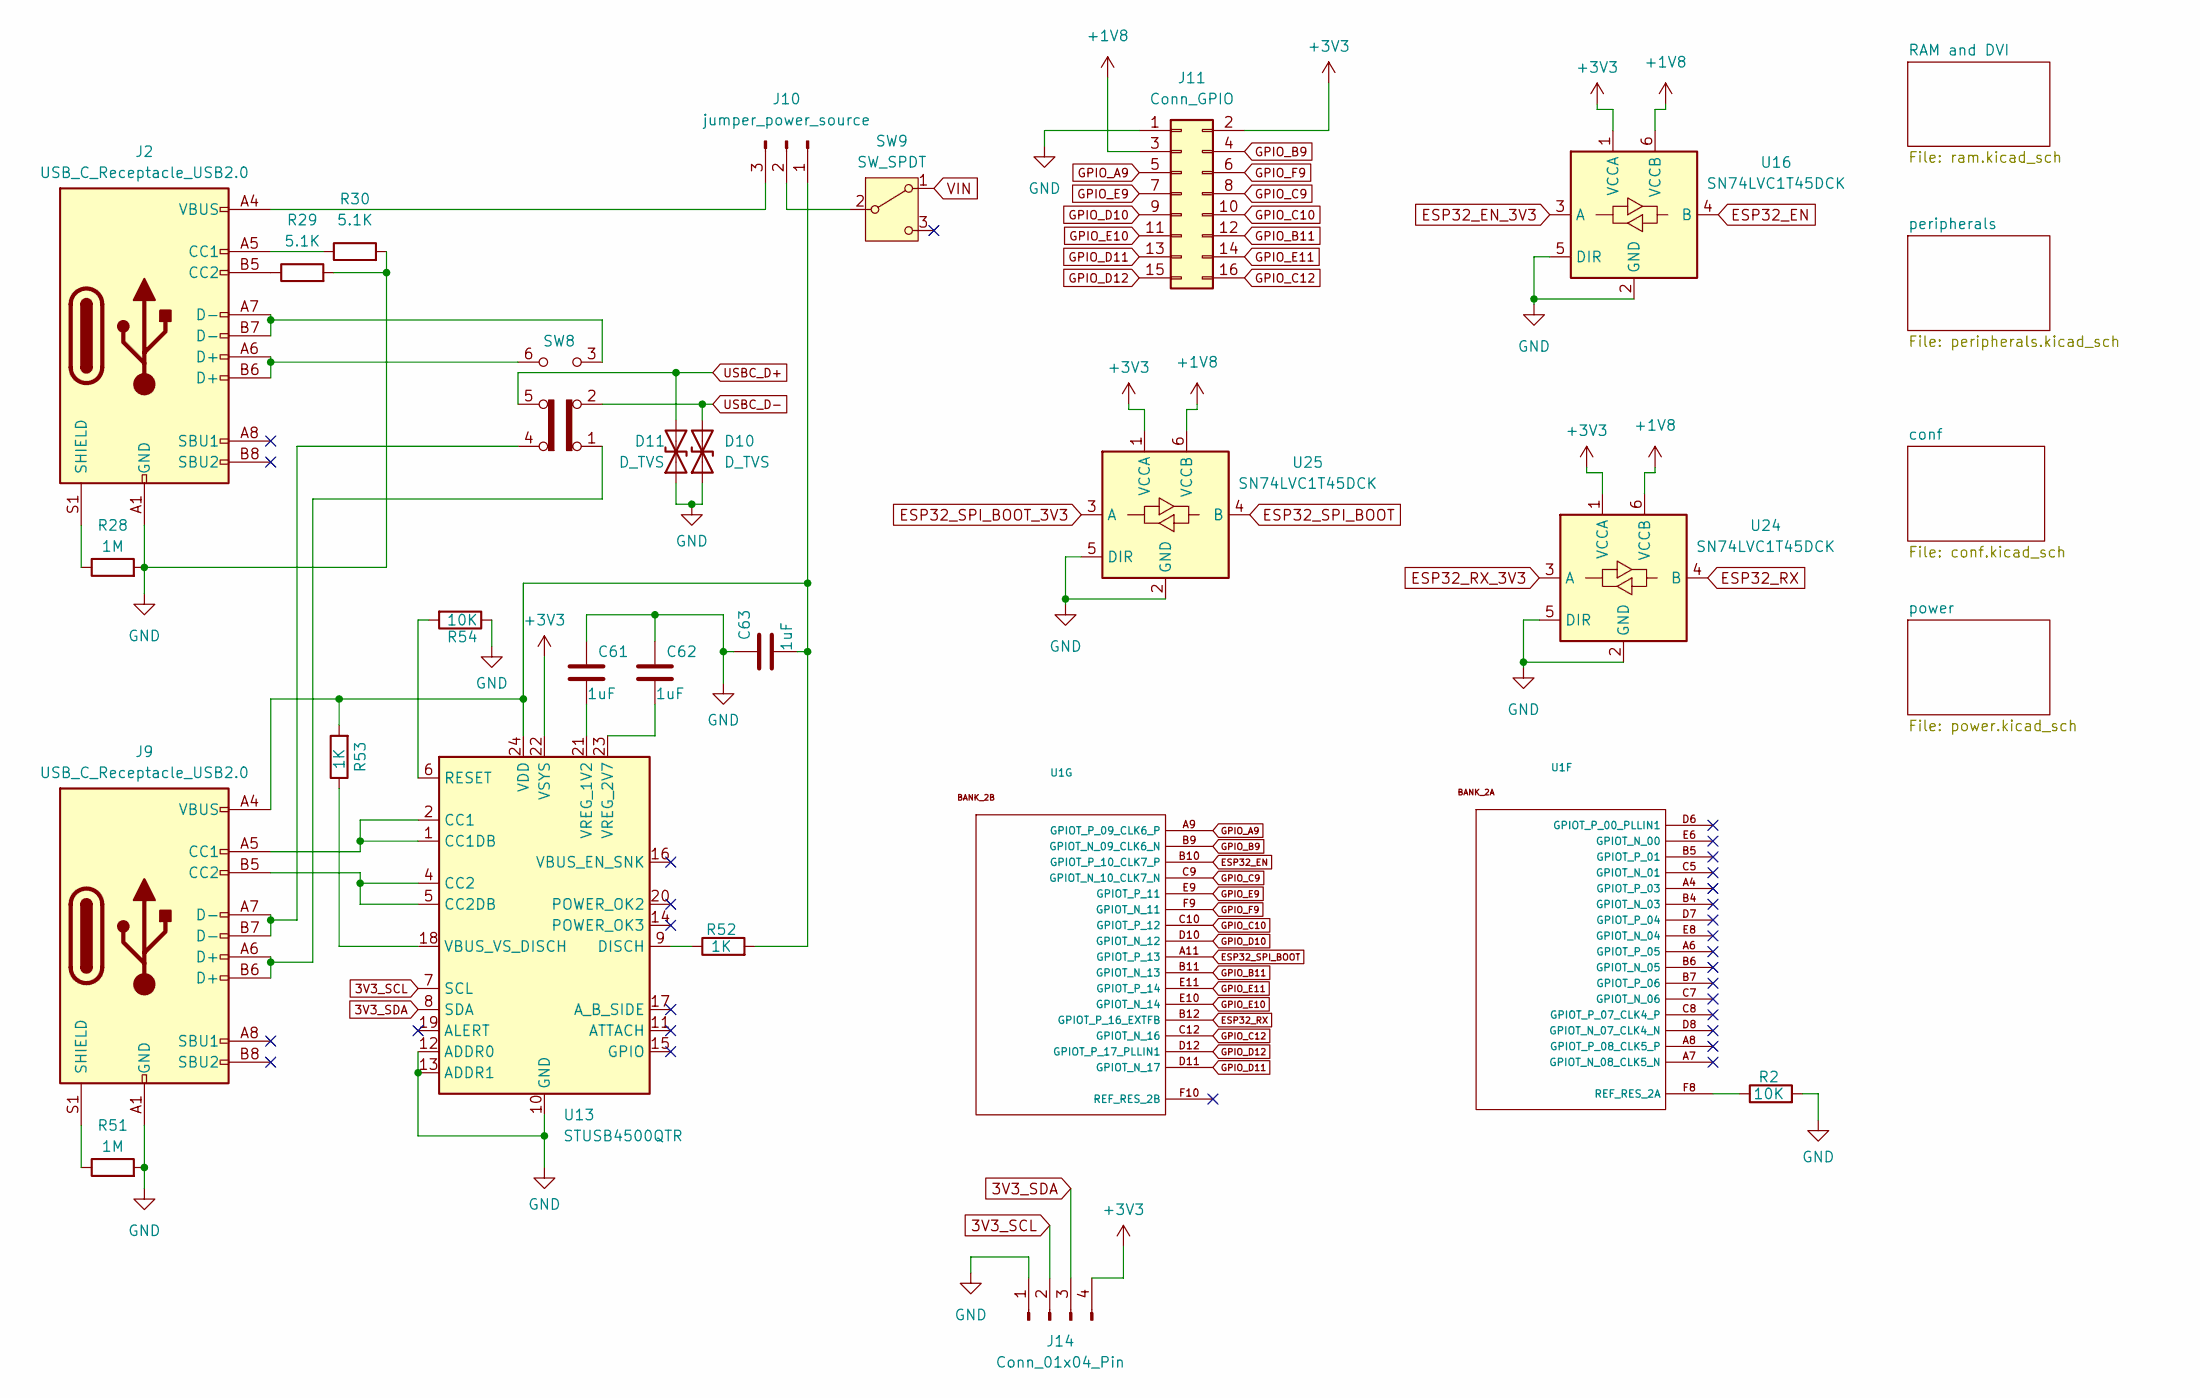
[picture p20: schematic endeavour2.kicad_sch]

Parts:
C61, C62, C63: 1uF; C_0603_1608Metric
D10, D11: D_TVS; D_0603_1608Metric
J2, J9: USB_C_Receptacle_USB2.0; USB_C_Receptacle_GCT_USB4105-xx-A_16P_TopMnt_Horizontal
J10: jumper_power_source; PinHeader_1x03_P2.54mm_Vertical
J11: Conn_GPIO; PinHeader_2x08_P2.54mm_Vertical
J14: Conn_01x04_Pin; PinHeader_1x04_P2.54mm_Vertical
R2, R54: 10K; R_0603_1608Metric
R28, R51: 1M; R_0603_1608Metric
R29, R30: 5.1K; R_0603_1608Metric
R52, R53: 1K; R_0603_1608Metric
SW8: SW_JS202011SCQN
SW9: SW_SPDT; mss3111
U1: Ti60F256; BGA-256_14.0x14.0mm_Layout16x16_P0.8mm_Ball0.45mm_Pad0.32mm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
U13: STUSB4500QTR; QFN-24-1EP_4x4mm_P0.5mm_EP2.7x2.7mm
U16, U24, U25: SN74LVC1T45DCK; SOT-363_SC-70-6

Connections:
3V3_SCL: J14.2, U13.7 (SCL); also elsewhere on the board
3V3_SDA: J14.3, U13.8 (SDA); also elsewhere on the board
+1V8: J11.3, U16.6 (VCCB), U24.6 (VCCB), U25.6 (VCCB); also elsewhere on the board
+3V3: J11.2, J14.4, U13.22 (VSYS), U16.1 (VCCA), U24.1 (VCCA), U25.1 (VCCA); also elsewhere on the board
ESP32_EN: U1.B10 (GPIOT_P_10_CLK7_P), U16.4 (B)
ESP32_EN_3V3: U16.3 (A); also elsewhere on the board
ESP32_RX: U1.B12 (GPIOT_P_16_EXTFB), U24.4 (B)
ESP32_RX_3V3: U24.3 (A); also elsewhere on the board
ESP32_SPI_BOOT: U1.A11 (GPIOT_P_13), U25.4 (B)
ESP32_SPI_BOOT_3V3: U25.3 (A); also elsewhere on the board
GND: C61.1, C62.1, C63.1, D10.1 (A1), D11.1 (A1), J2.A1 (GND), J2.A12 (GND), J2.B1 (GND), J2.B12 (GND), J9.A1 (GND), J9.A12 (GND), J9.B1 (GND), J9.B12 (GND), J11.1, J14.1, R2.2, R28.2, R29.2, R30.2, R51.2, R54.1, U13.10 (GND), U13.12 (ADDR0), U13.13 (ADDR1), U13.25 (GND), U16.2 (GND), U16.5 (DIR), U24.2 (GND), U24.5 (DIR), U25.2 (GND), U25.5 (DIR); also elsewhere on the board
GPIO_A9: J11.5, U1.A9 (GPIOT_P_09_CLK6_P)
GPIO_B9: J11.4, U1.B9 (GPIOT_N_09_CLK6_N)
GPIO_B11: J11.12, U1.B11 (GPIOT_N_13)
GPIO_C9: J11.8, U1.C9 (GPIOT_N_10_CLK7_N)
GPIO_C10: J11.10, U1.C10 (GPIOT_P_12)
GPIO_C12: J11.16, U1.C12 (GPIOT_N_16)
GPIO_D10: J11.9, U1.D10 (GPIOT_N_12)
GPIO_D11: J11.13, U1.D11 (GPIOT_N_17)
GPIO_D12: J11.15, U1.D12 (GPIOT_P_17_PLLIN1)
GPIO_E9: J11.7, U1.E9 (GPIOT_P_11)
GPIO_E10: J11.11, U1.E10 (GPIOT_N_14)
GPIO_E11: J11.14, U1.E11 (GPIOT_P_14)
GPIO_F9: J11.6, U1.F9 (GPIOT_N_11)
unnamed: J2.A5 (CC1), R30.1
unnamed: J2.B5 (CC2), R29.1
unnamed: J2.A6 (D+), J2.B6 (D+), SW8.6 (A)
unnamed: J2.A7 (D-), J2.B7 (D-), SW8.3 (C)
unnamed: J2.S1 (SHIELD), R28.1
unnamed: J9.A5 (CC1), U13.1 (CC1DB), U13.2 (CC1)
unnamed: J9.B5 (CC2), U13.4 (CC2), U13.5 (CC2DB)
unnamed: J9.A6 (D+), J9.B6 (D+), SW8.1 (A)
unnamed: J9.A7 (D-), J9.B7 (D-), SW8.4 (C)
unnamed: J9.S1 (SHIELD), R51.1
unnamed: C63.2, J9.A4 (VBUS), J9.A9 (VBUS), J9.B4 (VBUS), J9.B9 (VBUS), J10.1, R52.2, R53.2, U13.24 (VDD)
unnamed: J10.2, SW9.2 (B)
unnamed: J2.A4 (VBUS), J2.A9 (VBUS), J2.B4 (VBUS), J2.B9 (VBUS), J10.3
unnamed: R2.1, U1.F8 (REF_RES_2A)
unnamed: R52.1, U13.9 (DISCH)
unnamed: R54.2, U13.6 (RESET)
unnamed: R53.1, U13.18 (VBUS_VS_DISCH)
unnamed: C61.2, U13.21 (VREG_1V2)
unnamed: C62.2, U13.23 (VREG_2V7)
USBC_D+: D11.2 (A2), SW8.5 (B); also elsewhere on the board
USBC_D-: D10.2 (A2), SW8.2 (B); also elsewhere on the board
VIN: SW9.1 (A); also elsewhere on the board

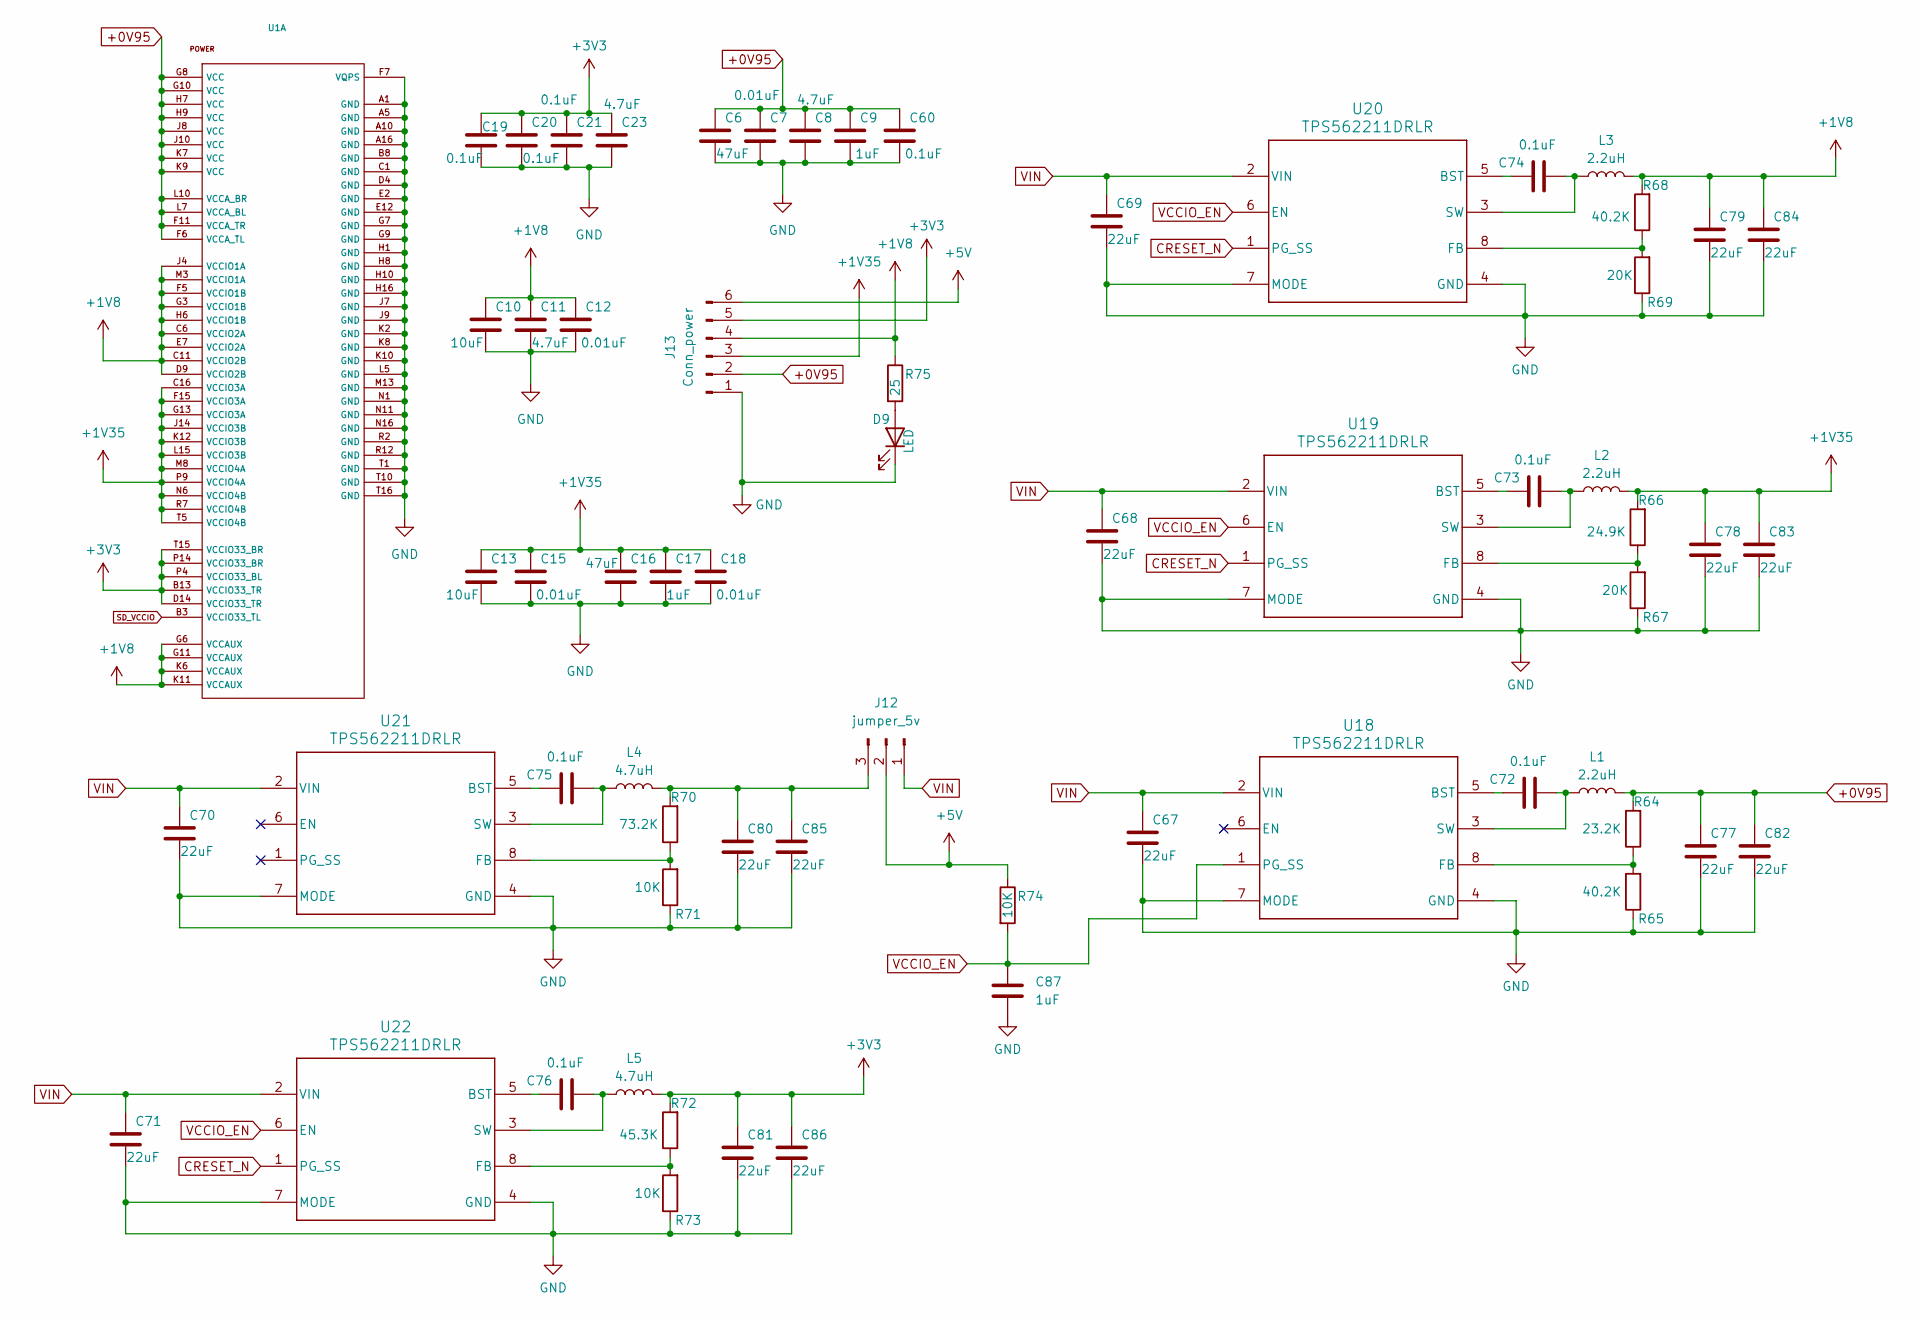
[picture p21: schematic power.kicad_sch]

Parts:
C6, C16: 47uF; C_0603_1608Metric
C7, C12, C15, C18: 0.01uF; C_0603_1608Metric
C8, C11, C23: 4.7uF; C_0603_1608Metric
C9, C17, C87: 1uF; C_0603_1608Metric
C10, C13: 10uF; C_0603_1608Metric
C19, C20, C21, C60, C72, C73, C74, C75, C76: 0.1uF; C_0603_1608Metric
C67, C68, C69, C70, C71, C77, C78, C79, C80, C81, C82, C83, C84, C85, C86: 22uF; C_0805_2012Metric
D9: LED; LED_0603_1608Metric
J12: jumper_5v; PinHeader_1x03_P2.54mm_Vertical
J13: Conn_power; PinHeader_1x06_P2.54mm_Vertical
L1, L2, L3: 2.2uH; L_1008_2520Metric
L4, L5: 4.7uH; L_1008_2520Metric
R64: 23.2K; R_0603_1608Metric
R65, R68: 40.2K; R_0603_1608Metric
R66: 24.9K; R_0603_1608Metric
R67, R69: 20K; R_0603_1608Metric
R70: 73.2K; R_0603_1608Metric
R71, R73, R74: 10K; R_0603_1608Metric
R72: 45.3K; R_0603_1608Metric
R75: 25; R_0603_1608Metric
U1: Ti60F256; BGA-256_14.0x14.0mm_Layout16x16_P0.8mm_Ball0.45mm_Pad0.32mm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
U18, U19, U20, U21, U22: TPS562211DRLR; DRL0008A-MFG

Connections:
+0V95: C6.1, C7.1, C8.1, C9.1, C60.1, C77.1, C82.1, J13.2, L1.2, R64.2, U1.F6 (VCCA_TL), U1.F11 (VCCA_TR), U1.G8 (VCC), U1.G10 (VCC), U1.H7 (VCC), U1.H9 (VCC), U1.J8 (VCC), U1.J10 (VCC), U1.K7 (VCC), U1.K9 (VCC), U1.L7 (VCCA_BL), U1.L10 (VCCA_BR)
+1V8: C10.1, C11.1, C12.1, C79.1, C84.1, J13.4, L3.2, R68.2, R75.1, U1.C6 (VCCIO2A), U1.C11 (VCCIO2B), U1.D9 (VCCIO2B), U1.E7 (VCCIO2A), U1.F5 (VCCIO1B), U1.G3 (VCCIO1B), U1.G6 (VCCAUX), U1.G11 (VCCAUX), U1.H6 (VCCIO1B), U1.J4 (VCCIO1A), U1.K6 (VCCAUX), U1.K11 (VCCAUX), U1.M3 (VCCIO1A); also elsewhere on the board
+1V35: C13.1, C15.1, C16.1, C17.1, C18.1, C78.1, C83.1, J13.3, L2.2, R66.2, U1.C16 (VCCIO3A), U1.F15 (VCCIO3A), U1.G13 (VCCIO3A), U1.J14 (VCCIO3B), U1.K12 (VCCIO3B), U1.L15 (VCCIO3B), U1.M8 (VCCIO4A), U1.N6 (VCCIO4B), U1.P9 (VCCIO4A), U1.R7 (VCCIO4B), U1.T5 (VCCIO4B); also elsewhere on the board
+3V3: C19.1, C20.1, C21.1, C23.1, C81.1, C86.1, J13.5, L5.2, R72.2, U1.B13 (VCCIO33_TR), U1.D14 (VCCIO33_TR), U1.P4 (VCCIO33_BL), U1.P14 (VCCIO33_BR), U1.T15 (VCCIO33_BR); also elsewhere on the board
+5V: J12.2, J13.6, R74.1; also elsewhere on the board
CRESET_N: U19.1 (PG_SS), U20.1 (PG_SS), U22.1 (PG_SS); also elsewhere on the board
GND: C6.2, C7.2, C8.2, C9.2, C10.2, C11.2, C12.2, C13.2, C15.2, C16.2, C17.2, C18.2, C19.2, C20.2, C21.2, C23.2, C60.2, C67.2, C68.2, C69.2, C70.2, C71.2, C77.2, C78.2, C79.2, C80.2, C81.2, C82.2, C83.2, C84.2, C85.2, C86.2, C87.2, D9.1 (K), J13.1, R65.1, R67.1, R69.1, R71.1, R73.1, U1.A1 (GND), U1.A5 (GND), U1.A10 (GND), U1.A16 (GND), U1.B8 (GND), U1.C1 (GND), U1.D4 (GND), U1.E2 (GND), U1.E12 (GND), U1.F7 (VQPS), U1.G7 (GND), U1.G9 (GND), U1.H1 (GND), U1.H8 (GND), U1.H10 (GND), U1.H16 (GND), U1.J7 (GND), U1.J9 (GND), U1.K2 (GND), U1.K8 (GND), U1.K10 (GND), U1.L5 (GND), U1.M13 (GND), U1.N1 (GND), U1.N11 (GND), U1.N16 (GND), U1.R2 (GND), U1.R12 (GND), U1.T1 (GND), U1.T10 (GND), U1.T16 (GND), U18.4 (GND), U18.7 (MODE), U19.4 (GND), U19.7 (MODE), U20.4 (GND), U20.7 (MODE), U21.4 (GND), U21.7 (MODE), U22.4 (GND), U22.7 (MODE); also elsewhere on the board
unnamed: D9.2 (A), R75.2
unnamed: C80.1, C85.1, J12.3, L4.2, R70.2
unnamed: C72.1, U18.5 (BST)
unnamed: R64.1, R65.2, U18.8 (FB)
unnamed: C72.2, L1.1, U18.3 (SW)
unnamed: C73.1, U19.5 (BST)
unnamed: R66.1, R67.2, U19.8 (FB)
unnamed: C73.2, L2.1, U19.3 (SW)
unnamed: C74.1, U20.5 (BST)
unnamed: R68.1, R69.2, U20.8 (FB)
unnamed: C74.2, L3.1, U20.3 (SW)
unnamed: C75.1, U21.5 (BST)
unnamed: R70.1, R71.2, U21.8 (FB)
unnamed: C75.2, L4.1, U21.3 (SW)
unnamed: C76.1, U22.5 (BST)
unnamed: R72.1, R73.2, U22.8 (FB)
unnamed: C76.2, L5.1, U22.3 (SW)
SD_VCCIO: U1.B3 (VCCIO33_TL); also elsewhere on the board
VCCIO_EN: C87.1, R74.2, U18.1 (PG_SS), U19.6 (EN), U20.6 (EN), U22.6 (EN)
VIN: C67.1, C68.1, C69.1, C70.1, C71.1, J12.1, U18.2 (VIN), U19.2 (VIN), U20.2 (VIN), U21.2 (VIN), U22.2 (VIN); also elsewhere on the board

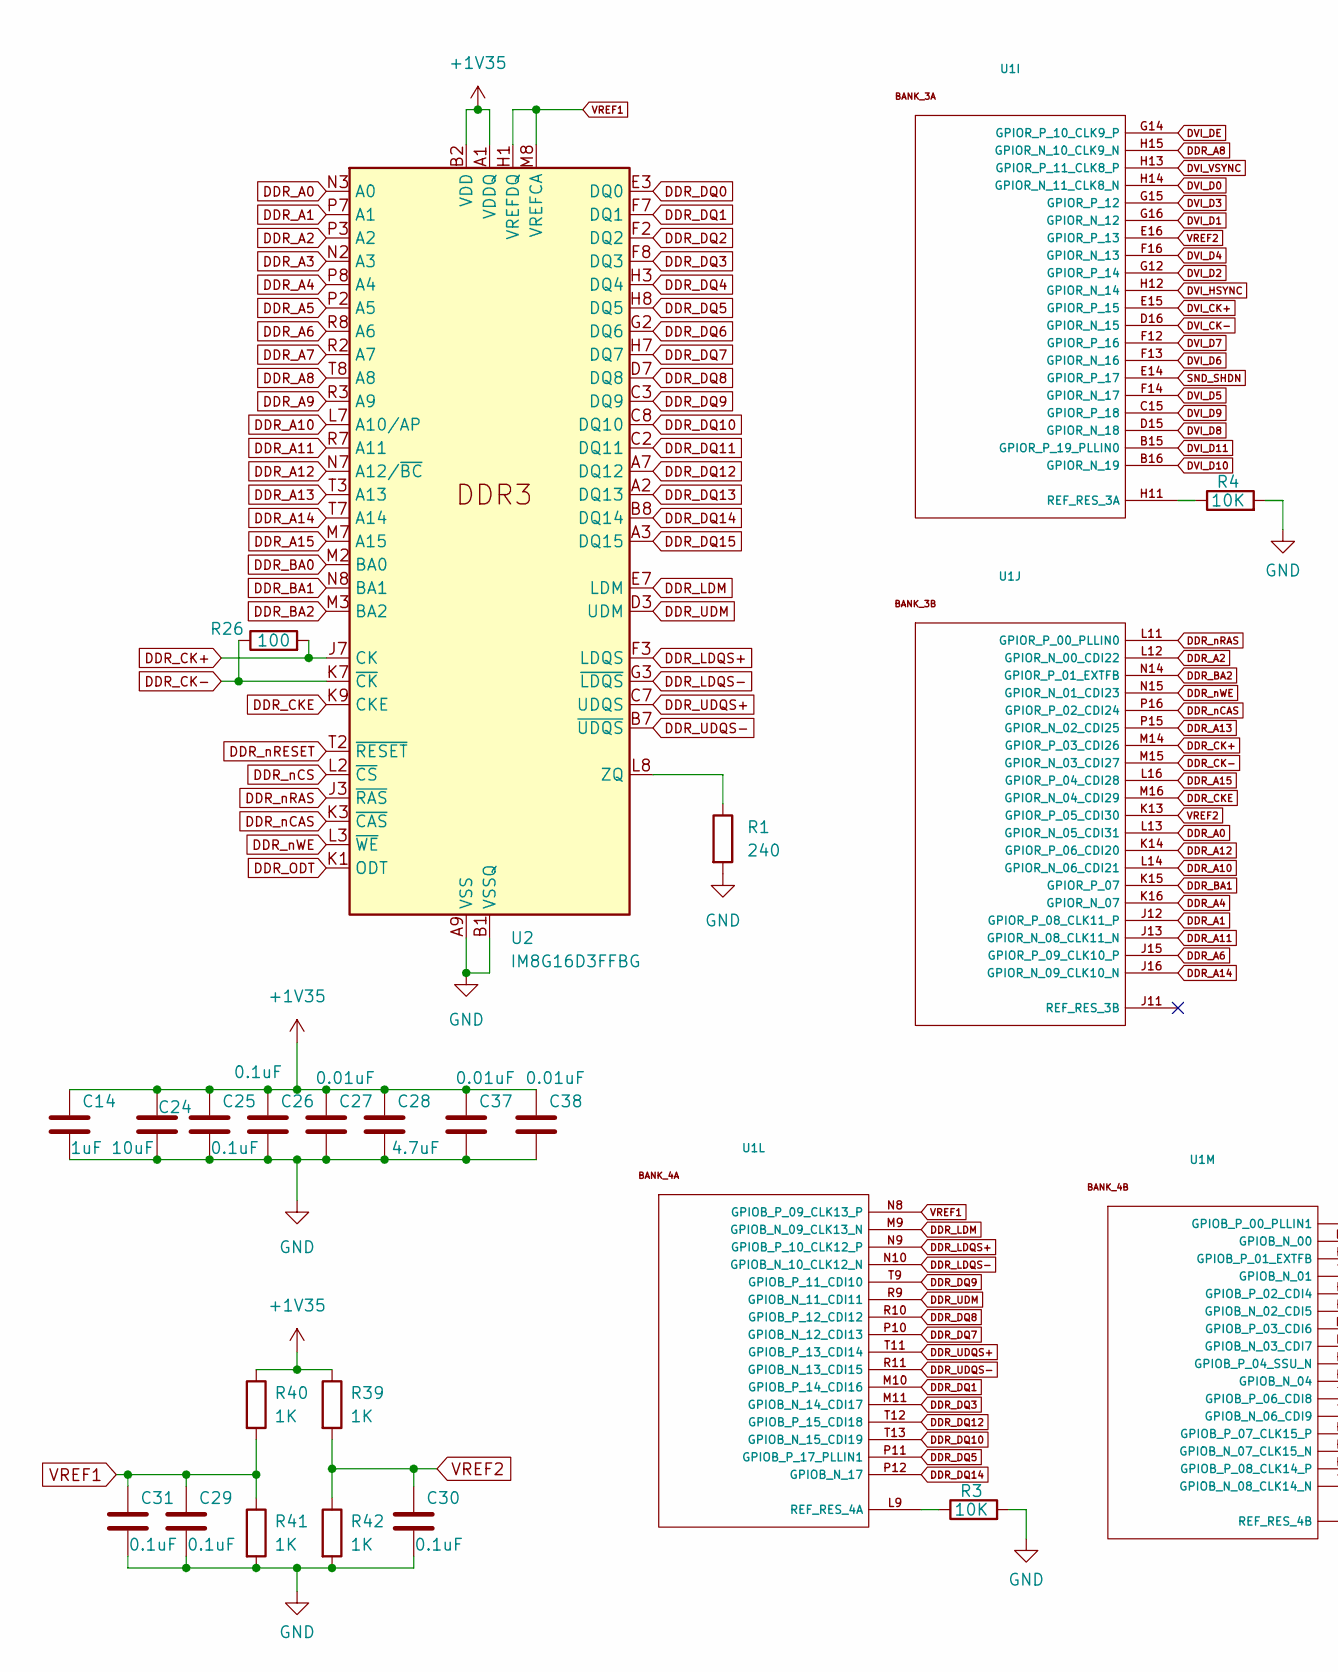
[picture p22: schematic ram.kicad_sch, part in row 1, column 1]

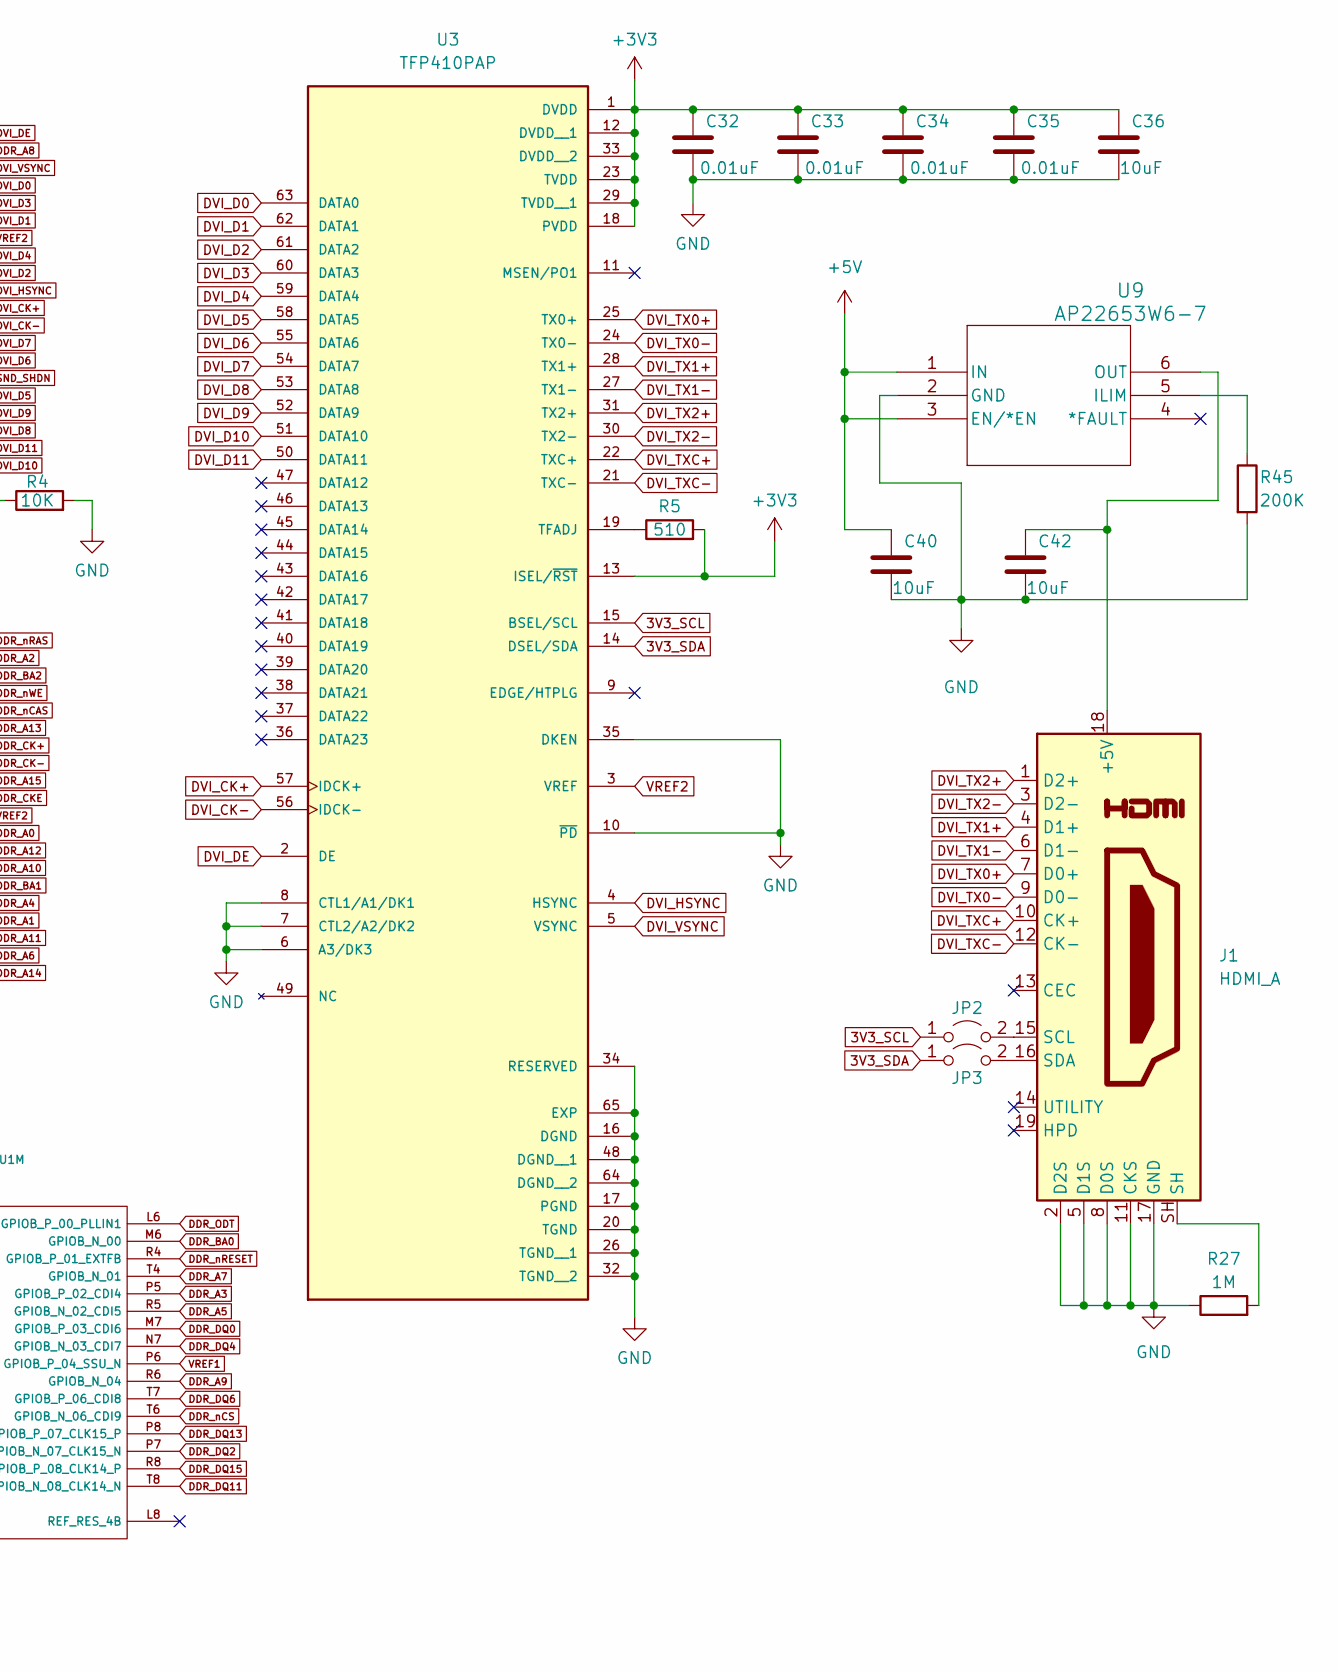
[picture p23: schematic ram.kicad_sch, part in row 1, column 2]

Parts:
C14: 1uF; C_0603_1608Metric
C24, C36, C40, C42: 10uF; C_0603_1608Metric
C25, C26, C29, C30, C31: 0.1uF; C_0603_1608Metric
C27, C32, C33, C34, C35, C37, C38: 0.01uF; C_0603_1608Metric
C28: 4.7uF; C_0603_1608Metric
J1: HDMI_A; HDMI_A_Amphenol_10029449-x01xLF_Horizontal
JP2, JP3: Jumper_2_Bridged; SolderJumper-2_P1.3mm_Open_RoundedPad1.0x1.5mm
R1: 240; R_0603_1608Metric
R3, R4: 10K; R_0603_1608Metric
R5: 510; R_0603_1608Metric
R26: 100; R_0603_1608Metric
R27: 1M; R_0603_1608Metric
R39, R40, R41, R42: 1K; R_0603_1608Metric
R45: 200K; R_0603_1608Metric
U1: Ti60F256; BGA-256_14.0x14.0mm_Layout16x16_P0.8mm_Ball0.45mm_Pad0.32mm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
U2: IM8G16D3FFBG; BGA-96_9.0x13.5mm_Layout2x3x16_P0.8mm
U3: TFP410PAP; IC_TFP410PAP; PARTREV D
U9: AP22653W6-7; SOT26_DIO

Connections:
3V3_SCL: JP2.1 (A), U3.15 (BSEL/SCL); also elsewhere on the board
3V3_SDA: JP3.1 (A), U3.14 (DSEL/SDA); also elsewhere on the board
+1V35: C14.1, C24.1, C25.1, C26.1, C27.1, C28.1, C37.1, C38.1, R39.1, R40.1, U2.A1 (VDDQ), U2.A8 (VDDQ), U2.B2 (VDD), U2.C1 (VDDQ), U2.C9 (VDDQ), U2.D2 (VDDQ), U2.D9 (VDD), U2.E9 (VDDQ), U2.F1 (VDDQ), U2.G7 (VDD), U2.H2 (VDDQ), U2.H9 (VDDQ), U2.K2 (VDD), U2.K8 (VDD), U2.N1 (VDD), U2.N9 (VDD), U2.R1 (VDD), U2.R9 (VDD); also elsewhere on the board
+3V3: C32.1, C33.1, C34.1, C35.1, C36.1, R5.2, U3.1 (DVDD), U3.12 (DVDD__1), U3.13 (ISEL/~RST), U3.18 (PVDD), U3.23 (TVDD), U3.29 (TVDD__1), U3.33 (DVDD__2); also elsewhere on the board
+5V: C40.1, U9.1 (IN), U9.3 (EN/*EN); also elsewhere on the board
DDR_A0: U1.L13 (GPIOR_N_05_CDI31), U2.N3 (A0)
DDR_A1: U1.J12 (GPIOR_P_08_CLK11_P), U2.P7 (A1)
DDR_A2: U1.L12 (GPIOR_N_00_CDI22), U2.P3 (A2)
DDR_A3: U1.P5 (GPIOB_P_02_CDI4), U2.N2 (A3)
DDR_A4: U1.K16 (GPIOR_N_07), U2.P8 (A4)
DDR_A5: U1.R5 (GPIOB_N_02_CDI5), U2.P2 (A5)
DDR_A6: U1.J15 (GPIOR_P_09_CLK10_P), U2.R8 (A6)
DDR_A7: U1.T4 (GPIOB_N_01), U2.R2 (A7)
DDR_A8: U1.H15 (GPIOR_N_10_CLK9_N), U2.T8 (A8)
DDR_A9: U1.R6 (GPIOB_N_04), U2.R3 (A9)
DDR_A10: U1.L14 (GPIOR_N_06_CDI21), U2.L7 (A10/AP)
DDR_A11: U1.J13 (GPIOR_N_08_CLK11_N), U2.R7 (A11)
DDR_A12: U1.K14 (GPIOR_P_06_CDI20), U2.N7 (A12/~BC)
DDR_A13: U1.P15 (GPIOR_N_02_CDI25), U2.T3 (A13)
DDR_A14: U1.J16 (GPIOR_N_09_CLK10_N), U2.T7 (A14)
DDR_A15: U1.L16 (GPIOR_P_04_CDI28), U2.M7 (A15)
DDR_BA0: U1.M6 (GPIOB_N_00), U2.M2 (BA0)
DDR_BA1: U1.K15 (GPIOR_P_07), U2.N8 (BA1)
DDR_BA2: U1.N14 (GPIOR_P_01_EXTFB), U2.M3 (BA2)
DDR_CK+: R26.2, U1.M14 (GPIOR_P_03_CDI26), U2.J7 (CK)
DDR_CK-: R26.1, U1.M15 (GPIOR_N_03_CDI27), U2.K7 (~CK)
DDR_CKE: U1.M16 (GPIOR_N_04_CDI29), U2.K9 (CKE)
DDR_DQ0: U1.M7 (GPIOB_P_03_CDI6), U2.E3 (DQ0)
DDR_DQ1: U1.M10 (GPIOB_P_14_CDI16), U2.F7 (DQ1)
DDR_DQ2: U1.P7 (GPIOB_N_07_CLK15_N), U2.F2 (DQ2)
DDR_DQ3: U1.M11 (GPIOB_N_14_CDI17), U2.F8 (DQ3)
DDR_DQ4: U1.N7 (GPIOB_N_03_CDI7), U2.H3 (DQ4)
DDR_DQ5: U1.P11 (GPIOB_P_17_PLLIN1), U2.H8 (DQ5)
DDR_DQ6: U1.T7 (GPIOB_P_06_CDI8), U2.G2 (DQ6)
DDR_DQ7: U1.P10 (GPIOB_N_12_CDI13), U2.H7 (DQ7)
DDR_DQ8: U1.R10 (GPIOB_P_12_CDI12), U2.D7 (DQ8)
DDR_DQ9: U1.T9 (GPIOB_P_11_CDI10), U2.C3 (DQ9)
DDR_DQ10: U1.T13 (GPIOB_N_15_CDI19), U2.C8 (DQ10)
DDR_DQ11: U1.T8 (GPIOB_N_08_CLK14_N), U2.C2 (DQ11)
DDR_DQ12: U1.T12 (GPIOB_P_15_CDI18), U2.A7 (DQ12)
DDR_DQ13: U1.P8 (GPIOB_P_07_CLK15_P), U2.A2 (DQ13)
DDR_DQ14: U1.P12 (GPIOB_N_17), U2.B8 (DQ14)
DDR_DQ15: U1.R8 (GPIOB_P_08_CLK14_P), U2.A3 (DQ15)
DDR_LDM: U1.M9 (GPIOB_N_09_CLK13_N), U2.E7 (LDM)
DDR_LDQS+: U1.N9 (GPIOB_P_10_CLK12_P), U2.F3 (LDQS)
DDR_LDQS-: U1.N10 (GPIOB_N_10_CLK12_N), U2.G3 (~LDQS)
DDR_ODT: U1.L6 (GPIOB_P_00_PLLIN1), U2.K1 (ODT)
DDR_UDM: U1.R9 (GPIOB_N_11_CDI11), U2.D3 (UDM)
DDR_UDQS+: U1.T11 (GPIOB_P_13_CDI14), U2.C7 (UDQS)
DDR_UDQS-: U1.R11 (GPIOB_N_13_CDI15), U2.B7 (~UDQS)
DDR_nCAS: U1.P16 (GPIOR_P_02_CDI24), U2.K3 (~CAS)
DDR_nCS: U1.T6 (GPIOB_N_06_CDI9), U2.L2 (~CS)
DDR_nRAS: U1.L11 (GPIOR_P_00_PLLIN0), U2.J3 (~RAS)
DDR_nRESET: U1.R4 (GPIOB_P_01_EXTFB), U2.T2 (~RESET)
DDR_nWE: U1.N15 (GPIOR_N_01_CDI23), U2.L3 (~WE)
DVI_CK+: U1.E15 (GPIOR_P_15), U3.57 (IDCK+)
DVI_CK-: U1.D16 (GPIOR_N_15), U3.56 (IDCK-)
DVI_D0: U1.H14 (GPIOR_N_11_CLK8_N), U3.63 (DATA0)
DVI_D1: U1.G16 (GPIOR_N_12), U3.62 (DATA1)
DVI_D2: U1.G12 (GPIOR_P_14), U3.61 (DATA2)
DVI_D3: U1.G15 (GPIOR_P_12), U3.60 (DATA3)
DVI_D4: U1.F16 (GPIOR_N_13), U3.59 (DATA4)
DVI_D5: U1.F14 (GPIOR_N_17), U3.58 (DATA5)
DVI_D6: U1.F13 (GPIOR_N_16), U3.55 (DATA6)
DVI_D7: U1.F12 (GPIOR_P_16), U3.54 (DATA7)
DVI_D8: U1.D15 (GPIOR_N_18), U3.53 (DATA8)
DVI_D9: U1.C15 (GPIOR_P_18), U3.52 (DATA9)
DVI_D10: U1.B16 (GPIOR_N_19), U3.51 (DATA10)
DVI_D11: U1.B15 (GPIOR_P_19_PLLIN0), U3.50 (DATA11)
DVI_DE: U1.G14 (GPIOR_P_10_CLK9_P), U3.2 (DE)
DVI_HSYNC: U1.H12 (GPIOR_N_14), U3.4 (HSYNC)
DVI_TX0+: J1.7 (D0+), U3.25 (TX0+)
DVI_TX0-: J1.9 (D0-), U3.24 (TX0-)
DVI_TX1+: J1.4 (D1+), U3.28 (TX1+)
DVI_TX1-: J1.6 (D1-), U3.27 (TX1-)
DVI_TX2+: J1.1 (D2+), U3.31 (TX2+)
DVI_TX2-: J1.3 (D2-), U3.30 (TX2-)
DVI_TXC+: J1.10 (CK+), U3.22 (TXC+)
DVI_TXC-: J1.12 (CK-), U3.21 (TXC-)
DVI_VSYNC: U1.H13 (GPIOR_P_11_CLK8_P), U3.5 (VSYNC)
GND: C14.2, C24.2, C25.2, C26.2, C27.2, C28.2, C29.2, C30.2, C31.2, C32.2, C33.2, C34.2, C35.2, C36.2, C37.2, C38.2, C40.2, C42.2, J1.2 (D2S), J1.5 (D1S), J1.8 (D0S), J1.11 (CKS), J1.17 (GND), R1.2, R3.2, R4.2, R27.1, R41.2, R42.2, R45.2, U2.A9 (VSS), U2.B1 (VSSQ), U2.B3 (VSS), U2.B9 (VSSQ), U2.D1 (VSSQ), U2.D8 (VSSQ), U2.E1 (VSS), U2.E2 (VSSQ), U2.E8 (VSSQ), U2.F9 (VSSQ), U2.G1 (VSSQ), U2.G8 (VSS), U2.G9 (VSSQ), U2.J2 (VSS), U2.J8 (VSS), U2.M1 (VSS), U2.M9 (VSS), U2.P1 (VSS), U2.P9 (VSS), U2.T1 (VSS), U2.T9 (VSS), U3.6 (A3/DK3), U3.7 (CTL2/A2/DK2), U3.8 (CTL1/A1/DK1), U3.10 (~PD), U3.16 (DGND), U3.17 (PGND), U3.20 (TGND), U3.26 (TGND__1), U3.32 (TGND__2), U3.34 (RESERVED), U3.35 (DKEN), U3.48 (DGND__1), U3.64 (DGND__2), U3.65 (EXP), U9.2 (GND); also elsewhere on the board
unnamed: C42.1, J1.18 (+5V), U9.6 (OUT)
unnamed: J1.SH, R27.2
unnamed: J1.15 (SCL), JP2.2 (B)
unnamed: J1.16 (SDA), JP3.2 (B)
unnamed: R4.1, U1.H11 (REF_RES_3A)
unnamed: R3.1, U1.L9 (REF_RES_4A)
unnamed: R1.1, U2.L8 (ZQ)
unnamed: R5.1, U3.19 (TFADJ)
unnamed: R45.1, U9.5 (ILIM)
SND_SHDN: U1.E14 (GPIOR_P_17); also elsewhere on the board
VREF1: C29.1, C31.1, R40.2, R41.1, U1.N8 (GPIOB_P_09_CLK13_P), U1.P6 (GPIOB_P_04_SSU_N), U2.H1 (VREFDQ), U2.M8 (VREFCA)
VREF2: C30.1, R39.2, R42.1, U1.E16 (GPIOR_P_13), U1.K13 (GPIOR_P_05_CDI30), U3.3 (VREF)

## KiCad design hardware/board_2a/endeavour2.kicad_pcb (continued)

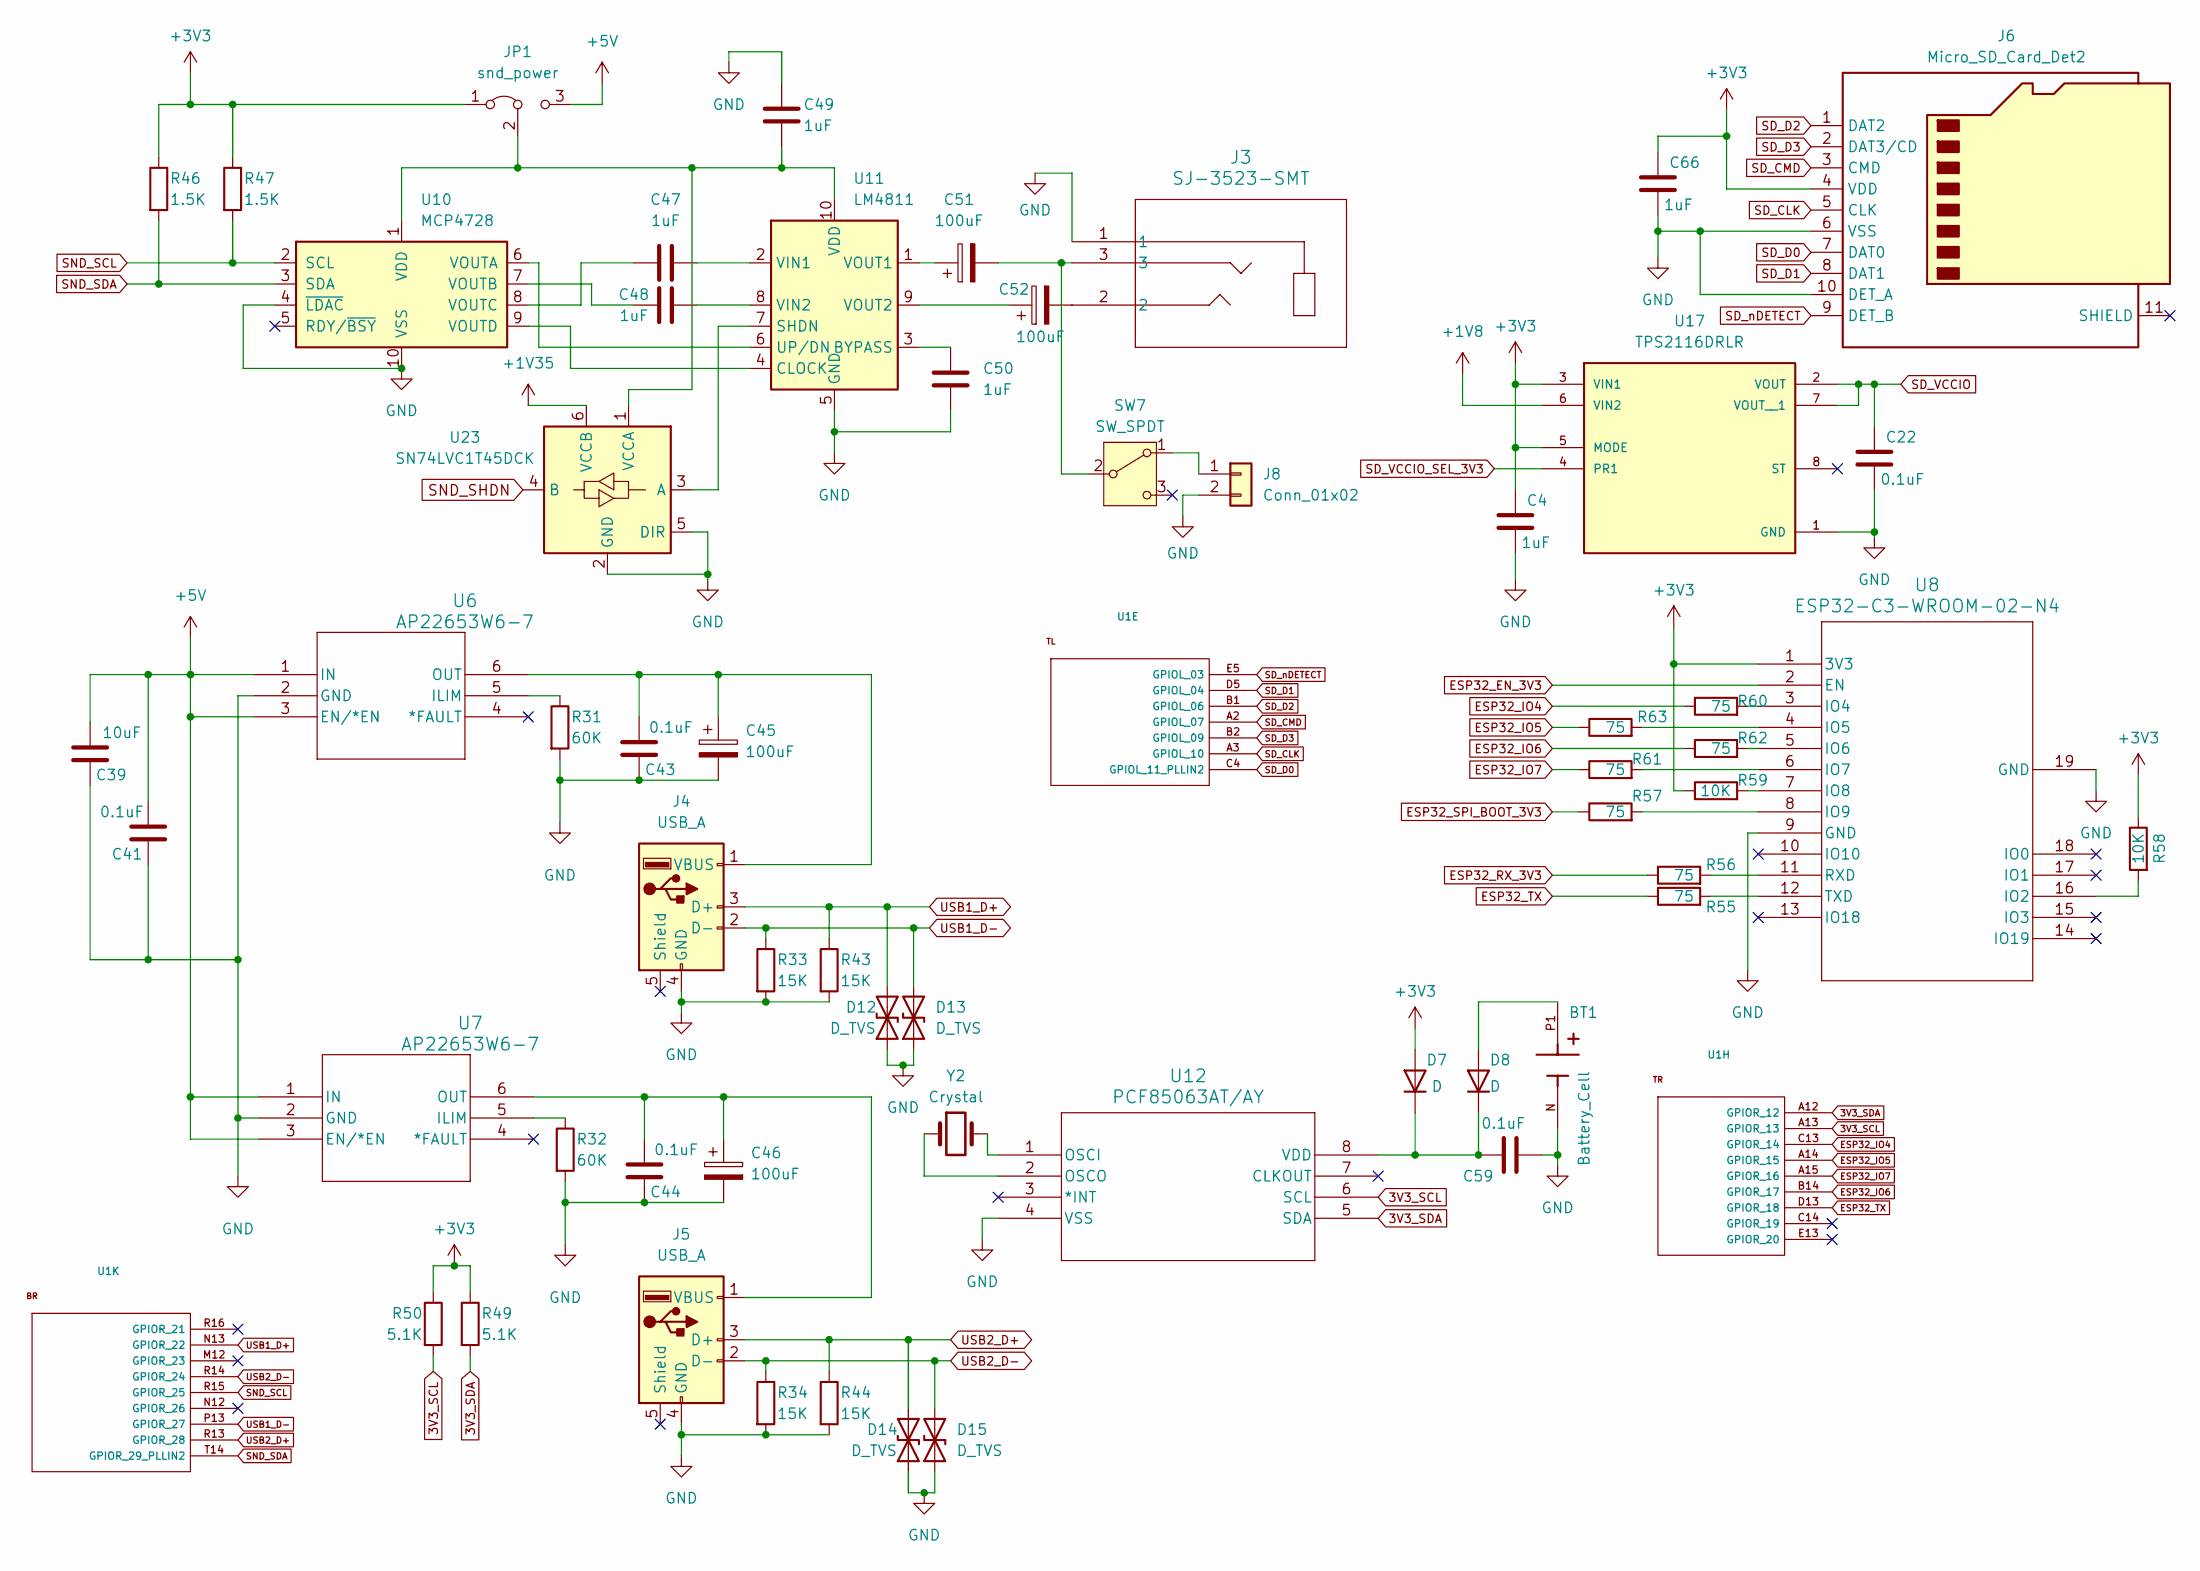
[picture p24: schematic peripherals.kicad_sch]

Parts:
BT1: Battery_Cell; BAT_2989; PARTREV A
C4, C47, C48, C49, C50, C66: 1uF; C_0603_1608Metric
C22, C41, C43, C44, C59: 0.1uF; C_0603_1608Metric
C39: 10uF; C_0603_1608Metric
C45, C46: 100uF; CP_EIA-3528-12_Kemet-T
C51, C52: 100uF; CP_Elec_5x5.3
D7, D8: D; D_SOD-323
D12, D13, D14, D15: D_TVS; D_0603_1608Metric
J3: SJ-3523-SMT; SJ-3523-SMT_CUD
J4, J5: USB_A; USB_A_Receptacle_GCT_USB1046
J6: Micro_SD_Card_Det2; microSD_HC_Molex_104031-0811
J8: Conn_01x02; PinHeader_1x02_P2.54mm_Vertical
JP1: snd_power; SolderJumper-3_P1.3mm_Open_Pad1.0x1.5mm
R31, R32: 60K; R_0603_1608Metric
R33, R34, R43, R44: 15K; R_0603_1608Metric
R46, R47: 1.5K; R_0603_1608Metric
R49, R50: 5.1K; R_0603_1608Metric
R55, R56, R57, R60, R61, R62, R63: 75; R_0603_1608Metric
R58, R59: 10K; R_0603_1608Metric
SW7: SW_SPDT; SW_Slide_SPDT_Angled_CK_OS102011MA1Q
U1: Ti60F256; BGA-256_14.0x14.0mm_Layout16x16_P0.8mm_Ball0.45mm_Pad0.32mm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
U6, U7: AP22653W6-7; SOT26_DIO
U8: ESP32-C3-WROOM-02-N4; ESP32-C3-WROOM-02
U10: MCP4728; MSOP-10_3x3mm_P0.5mm
U11: LM4811; TSSOP-10_3x3mm_P0.5mm
U12: PCF85063AT/AY; SOIC-8_3.9x4.9mm_P1.27mm
U17: TPS2116DRLR; SOTFL50P160X60-8N; PARTREV A
U23: SN74LVC1T45DCK; SOT-363_SC-70-6
Y2: Crystal; Crystal_SMD_MicroCrystal_CC7V-T1A-2Pin_3.2x1.5mm_HandSolder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

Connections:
3V3_SCL: R50.2, U1.A13 (GPIOR_13), U12.6 (SCL); also elsewhere on the board
3V3_SDA: R49.2, U1.A12 (GPIOR_12), U12.5 (SDA); also elsewhere on the board
+1V8: U17.6 (VIN2); also elsewhere on the board
+1V35: U23.6 (VCCB); also elsewhere on the board
+3V3: C4.1, C66.1, D7.2 (A), J6.4 (VDD), JP1.1 (A), R46.1, R47.1, R49.1, R50.1, R58.1, R59.1, U8.1 (3V3), U17.3 (VIN1), U17.5 (MODE); also elsewhere on the board
+5V: C39.2, C41.2, JP1.3 (B), U6.1 (IN), U6.3 (EN/*EN), U7.1 (IN), U7.3 (EN/*EN); also elsewhere on the board
ESP32_EN_3V3: U8.2 (EN); also elsewhere on the board
ESP32_IO4: R60.1, U1.C13 (GPIOR_14)
ESP32_IO5: R63.1, U1.A14 (GPIOR_15)
ESP32_IO6: R62.1, U1.B14 (GPIOR_17)
ESP32_IO7: R61.1, U1.A15 (GPIOR_16)
ESP32_RX_3V3: R56.1; also elsewhere on the board
ESP32_SPI_BOOT_3V3: R57.1; also elsewhere on the board
ESP32_TX: R55.1, U1.D13 (GPIOR_18)
GND: BT1.N, C4.2, C22.2, C39.1, C41.1, C43.1, C44.1, C45.2, C46.2, C49.1, C50.2, C59.2, C66.2, D12.1 (A1), D13.1 (A1), D14.1 (A1), D15.1 (A1), J3.1, J4.4 (GND), J5.4 (GND), J6.6 (VSS), J6.10 (DET_A), J8.2, R31.2, R32.2, R33.2, R34.2, R43.2, R44.2, U6.2 (GND), U7.2 (GND), U8.9 (GND), U8.19 (GND), U10.4 (~LDAC), U10.10 (VSS), U11.5 (GND), U12.4 (VSS), U17.1 (GND), U23.2 (GND), U23.5 (DIR); also elsewhere on the board
unnamed: C52.2, J3.2
unnamed: C59.1, D7.1 (K), D8.1 (K), U12.8 (VDD)
unnamed: BT1.P1, D8.2 (A)
unnamed: C43.2, C45.1, J4.1 (VBUS), U6.6 (OUT)
unnamed: C44.2, C46.1, J5.1 (VBUS), U7.6 (OUT)
unnamed: J8.1, SW7.1 (A)
unnamed: C49.2, JP1.2 (C), U10.1 (VDD), U11.10 (VDD), U23.1 (VCCA)
unnamed: C51.2, J3.3, SW7.2 (B)
unnamed: R31.1, U6.5 (ILIM)
unnamed: R32.1, U7.5 (ILIM)
unnamed: R58.2, U8.16 (IO2)
unnamed: R60.2, U8.3 (IO4)
unnamed: R63.2, U8.4 (IO5)
unnamed: R62.2, U8.5 (IO6)
unnamed: R61.2, U8.6 (IO7)
unnamed: R59.2, U8.7 (IO8)
unnamed: R57.2, U8.8 (IO9)
unnamed: R56.2, U8.11 (RXD)
unnamed: R55.2, U8.12 (TXD)
unnamed: U10.6 (VOUTA), U11.6 (UP/DN)
unnamed: C48.1, U10.7 (VOUTB)
unnamed: C47.1, U10.8 (VOUTC)
unnamed: U10.9 (VOUTD), U11.4 (CLOCK)
unnamed: C50.1, U11.3 (BYPASS)
unnamed: U11.7 (SHDN), U23.3 (A)
unnamed: C47.2, U11.2 (VIN1)
unnamed: C48.2, U11.8 (VIN2)
unnamed: C51.1, U11.1 (VOUT1)
unnamed: C52.1, U11.9 (VOUT2)
unnamed: U12.1 (OSCI), Y2.2
unnamed: U12.2 (OSCO), Y2.1
SD_CLK: J6.5 (CLK), U1.A3 (GPIOL_10)
SD_CMD: J6.3 (CMD), U1.A2 (GPIOL_07)
SD_D0: J6.7 (DAT0), U1.C4 (GPIOL_11_PLLIN2)
SD_D1: J6.8 (DAT1), U1.D5 (GPIOL_04)
SD_D2: J6.1 (DAT2), U1.B1 (GPIOL_06)
SD_D3: J6.2 (DAT3/CD), U1.B2 (GPIOL_09)
SD_VCCIO: C22.1, U17.2 (VOUT), U17.7 (VOUT__1); also elsewhere on the board
SD_VCCIO_SEL_3V3: U17.4 (PR1); also elsewhere on the board
SD_nDETECT: J6.9 (DET_B), U1.E5 (GPIOL_03)
SND_SCL: R47.2, U1.R15 (GPIOR_25), U10.2 (SCL)
SND_SDA: R46.2, U1.T14 (GPIOR_29_PLLIN2), U10.3 (SDA)
SND_SHDN: U23.4 (B); also elsewhere on the board
USB1_D+: D12.2 (A2), J4.3 (D+), R43.1, U1.N13 (GPIOR_22)
USB1_D-: D13.2 (A2), J4.2 (D-), R33.1, U1.P13 (GPIOR_27)
USB2_D+: D14.2 (A2), J5.3 (D+), R44.1, U1.R13 (GPIOR_28)
USB2_D-: D15.2 (A2), J5.2 (D-), R34.1, U1.R14 (GPIOR_24)

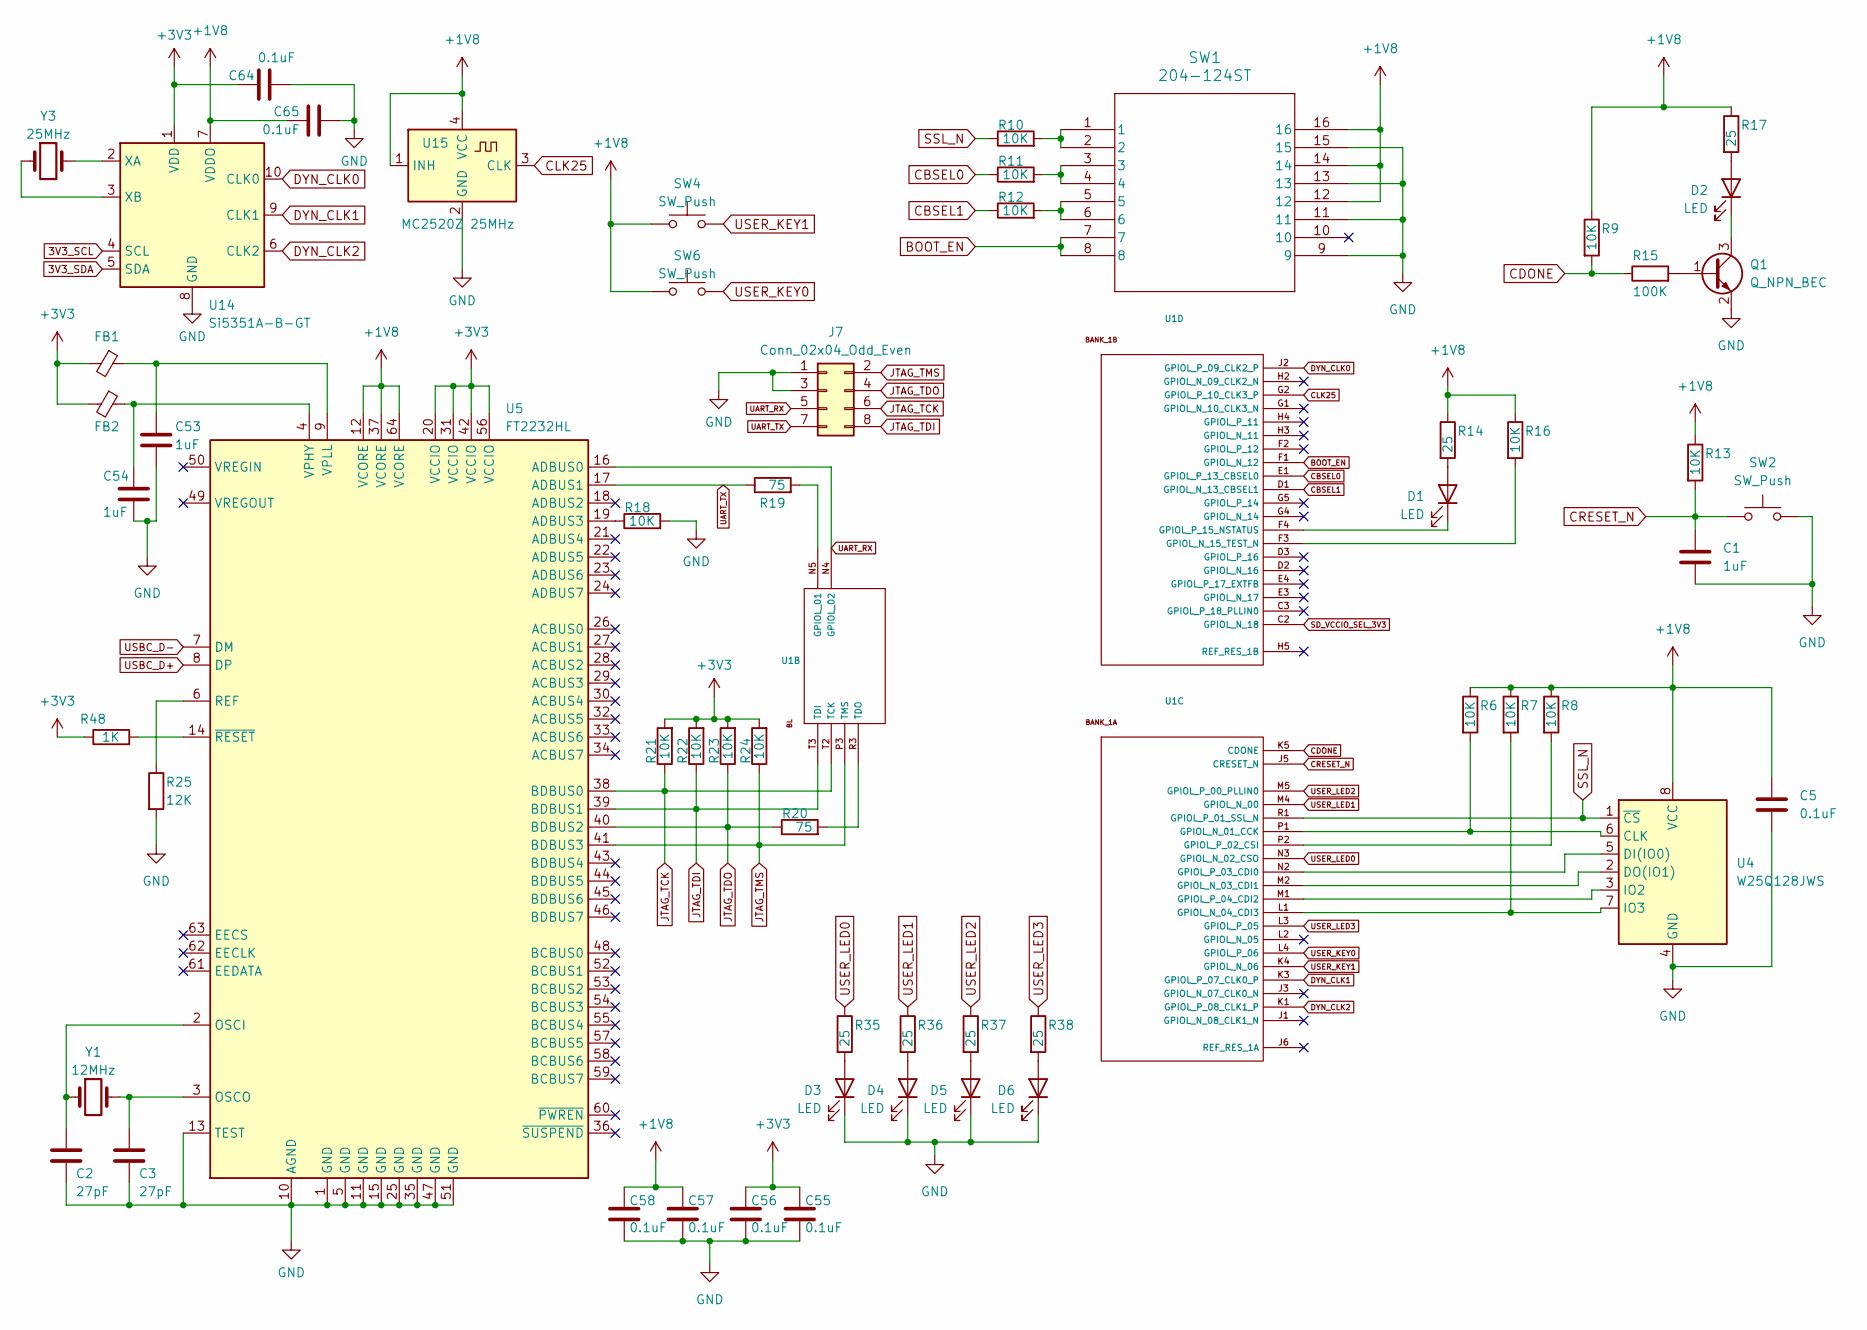
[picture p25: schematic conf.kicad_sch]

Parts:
C1, C53, C54: 1uF; C_0603_1608Metric
C2, C3: 27pF; C_0603_1608Metric
C5, C55, C56, C57, C58, C64, C65: 0.1uF; C_0603_1608Metric
D1, D2, D3, D4, D5, D6: LED; LED_0603_1608Metric
FB1, FB2: L_0603_1608Metric
J7: Conn_02x04_Odd_Even; PinHeader_2x04_P2.54mm_Vertical
Q1: Q_NPN_BEC; SC-59
R6, R7, R8, R9, R10, R11, R12, R13, R16, R18, R21, R22, R23, R24: 10K; R_0603_1608Metric
R14, R17, R35, R36, R37, R38: 25; R_0603_1608Metric
R15: 100K; R_0603_1608Metric
R19, R20: 75; R_0603_1608Metric
R25: 12K; R_0603_1608Metric
R48: 1K; R_0603_1608Metric
SW1: 204-124ST; SPDT_204-124_CTS
SW2, SW4, SW6: SW_Push; SW_PUSH_6mm
U1: Ti60F256; BGA-256_14.0x14.0mm_Layout16x16_P0.8mm_Ball0.45mm_Pad0.32mm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
U4: W25Q128JWS; SOIC-8_5.23x5.23mm_P1.27mm
U5: FT2232HL; LQFP-64_10x10mm_P0.5mm
U14: Si5351A-B-GT; MSOP-10_3x3mm_P0.5mm
U15: MC2520Z 25MHz; Oscillator_SMD_Kyocera_KC2520Z-4Pin_2.5x2.0mm
Y1: 12MHz; XTAL_ECS-120-20-3X-TR
Y3: 25MHz; XTAL_ECS-120-20-3X-TR

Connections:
3V3_SCL: U14.4 (SCL); also elsewhere on the board
3V3_SDA: U14.5 (SDA); also elsewhere on the board
+1V8: C5.1, C57.1, C58.1, C65.1, R6.1, R7.1, R8.1, R9.1, R13.1, R14.1, R16.1, R17.1, SW1.12, SW1.14, SW1.16, SW4.1, SW6.1, U4.8 (VCC), U5.12 (VCORE), U5.37 (VCORE), U5.64 (VCORE), U14.7 (VDDO), U15.1 (INH), U15.4 (VCC); also elsewhere on the board
+3V3: C55.1, C56.1, C64.1, FB1.2, FB2.2, R21.2, R22.2, R23.2, R24.2, R48.1, U5.20 (VCCIO), U5.31 (VCCIO), U5.42 (VCCIO), U5.56 (VCCIO), U14.1 (VDD); also elsewhere on the board
BOOT_EN: SW1.7, SW1.8, U1.F1 (GPIOL_N_12)
CBSEL0: R11.1, U1.E1 (GPIOL_P_13_CBSEL0)
CBSEL1: R12.1, U1.D1 (GPIOL_N_13_CBSEL1)
CDONE: R9.2, R15.1, U1.K5 (CDONE)
CLK25: U1.G2 (GPIOL_P_10_CLK3_P), U15.3 (CLK)
CRESET_N: C1.1, R13.2, SW2.1, U1.J5 (CRESET_N); also elsewhere on the board
DYN_CLK0: U1.J2 (GPIOL_P_09_CLK2_P), U14.10 (CLK0)
DYN_CLK1: U1.K3 (GPIOL_P_07_CLK0_P), U14.9 (CLK1)
DYN_CLK2: U1.K1 (GPIOL_P_08_CLK1_P), U14.6 (CLK2)
GND: C1.2, C2.2, C3.2, C5.2, C53.2, C54.2, C55.2, C56.2, C57.2, C58.2, C64.2, C65.2, D3.1 (K), D4.1 (K), D5.1 (K), D6.1 (K), J7.1, J7.3, Q1.2 (E), R18.2, R25.2, SW1.9, SW1.11, SW1.13, SW1.15, SW2.2, U4.4 (GND), U5.1 (GND), U5.5 (GND), U5.10 (AGND), U5.11 (GND), U5.13 (TEST), U5.15 (GND), U5.25 (GND), U5.35 (GND), U5.47 (GND), U5.51 (GND), U14.8 (GND), U15.2 (GND); also elsewhere on the board
JTAG_TCK: J7.6, R21.1, U1.T2 (TCK), U5.38 (BDBUS0)
JTAG_TDI: J7.8, R22.1, U1.T3 (TDI), U5.39 (BDBUS1)
JTAG_TDO: J7.4, R20.1, R23.1, U5.40 (BDBUS2)
JTAG_TMS: J7.2, R24.1, U1.P3 (TMS), U5.41 (BDBUS3)
unnamed: D1.2 (A), R14.2
unnamed: D1.1 (K), U1.F4 (GPIOL_P_15_NSTATUS)
unnamed: D2.2 (A), R17.2
unnamed: D2.1 (K), Q1.3 (C)
unnamed: D3.2 (A), R35.2
unnamed: D4.2 (A), R36.2
unnamed: D5.2 (A), R37.2
unnamed: D6.2 (A), R38.2
unnamed: Q1.1 (B), R15.2
unnamed: R10.2, SW1.1, SW1.2
unnamed: R11.2, SW1.3, SW1.4
unnamed: R12.2, SW1.5, SW1.6
unnamed: R19.2, U1.N5 (GPIOL_01)
unnamed: R20.2, U1.R3 (TDO)
unnamed: R6.2, U1.P1 (GPIOL_N_01_CCK), U4.6 (CLK)
unnamed: U1.M2 (GPIOL_N_03_CDI1), U4.2 (DO(IO1))
unnamed: R7.2, U1.L1 (GPIOL_N_04_CDI3), U4.7 (IO3)
unnamed: R8.2, U1.P2 (GPIOL_P_02_CSI)
unnamed: U1.N2 (GPIOL_P_03_CDI0), U4.5 (DI(IO0))
unnamed: U1.M1 (GPIOL_P_04_CDI2), U4.3 (IO2)
unnamed: R16.2, U1.F3 (GPIOL_N_15_TEST_N)
unnamed: R18.1, U5.19 (ADBUS3)
unnamed: C2.1, U5.2 (OSCI), Y1.1
unnamed: C3.1, U5.3 (OSCO), Y1.2
unnamed: R25.1, U5.6 (REF)
unnamed: C54.1, FB2.1, U5.4 (VPHY)
unnamed: C53.1, FB1.1, U5.9 (VPLL)
unnamed: R48.2, U5.14 (~RESET)
unnamed: U14.2 (XA), Y3.2
unnamed: U14.3 (XB), Y3.1
SD_VCCIO_SEL_3V3: U1.C2 (GPIOL_N_18); also elsewhere on the board
SSL_N: R10.1, U1.R1 (GPIOL_P_01_SSL_N), U4.1 (~CS)
UART_RX: J7.5, U1.N4 (GPIOL_02), U5.16 (ADBUS0)
UART_TX: J7.7, R19.1, U5.17 (ADBUS1)
USBC_D+: U5.8 (DP); also elsewhere on the board
USBC_D-: U5.7 (DM); also elsewhere on the board
USER_KEY0: SW6.2, U1.L4 (GPIOL_P_06)
USER_KEY1: SW4.2, U1.K4 (GPIOL_N_06)
USER_LED0: R35.1, U1.N3 (GPIOL_N_02_CSO)
USER_LED1: R36.1, U1.M4 (GPIOL_N_00)
USER_LED2: R37.1, U1.M5 (GPIOL_P_00_PLLIN0)
USER_LED3: R38.1, U1.L3 (GPIOL_P_05)

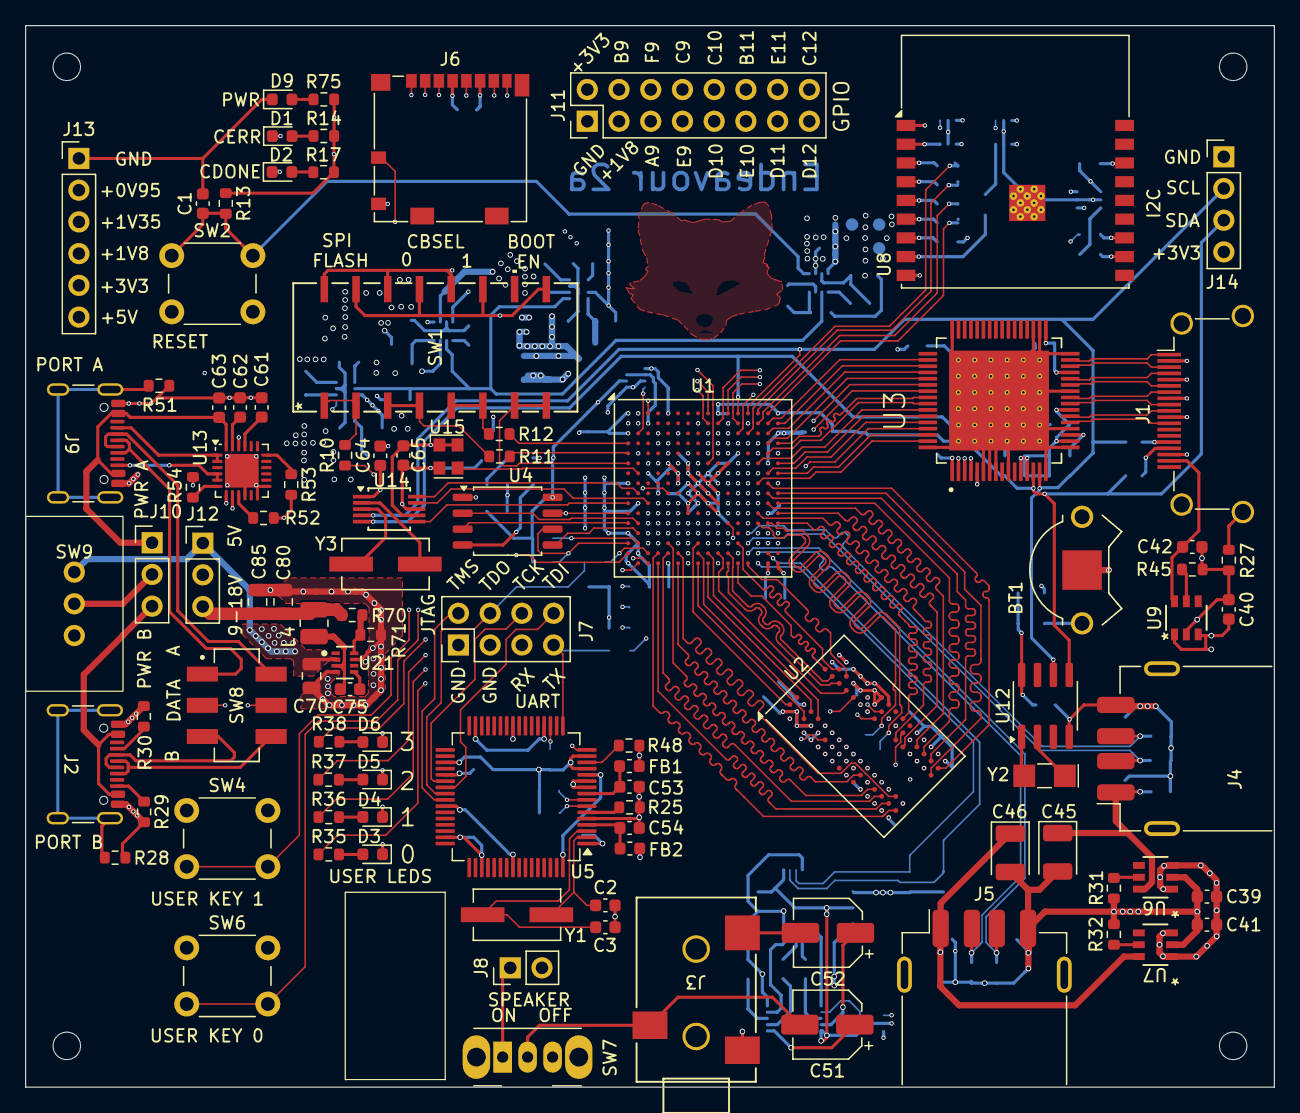
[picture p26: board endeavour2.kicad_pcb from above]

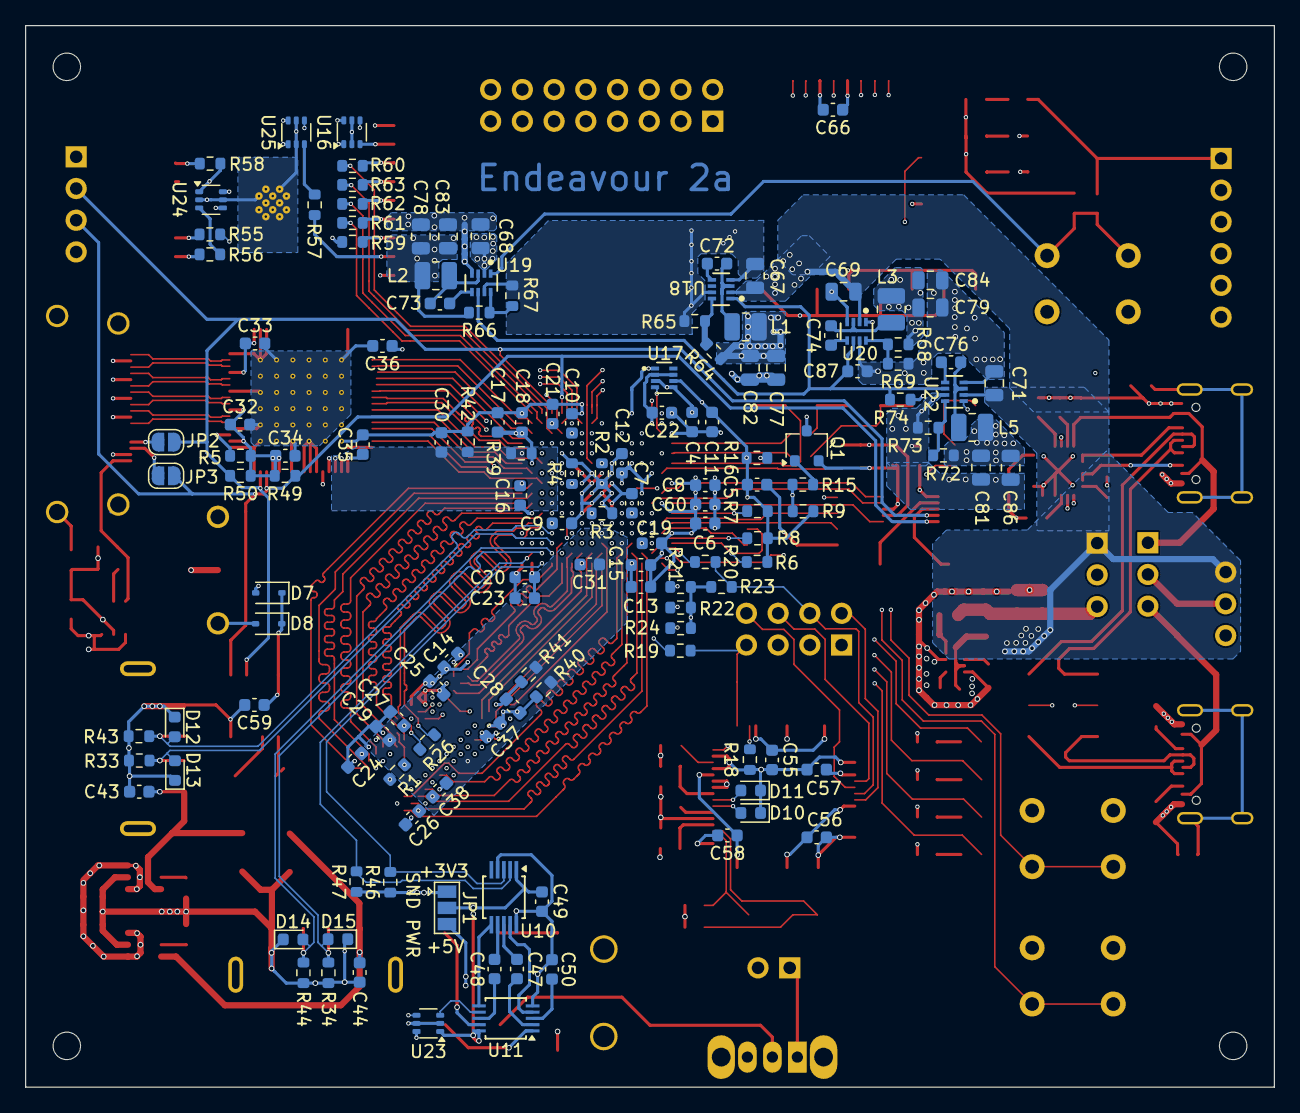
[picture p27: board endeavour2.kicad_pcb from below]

Board: 6 copper layers, 100.0 x 85.0 mm, 238 parts (141 on the bottom side), 257 nets.

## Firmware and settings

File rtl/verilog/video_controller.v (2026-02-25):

module VideoController #(parameter ADDRESS_WIDTH) (
  input clk,
  input reset,
  input pixel_clk,

  output reg [7:0] data_red,
  output reg [7:0] data_green,
  output reg [7:0] data_blue,
  output           data_enable,
  output reg hSync,
  output reg vSync,

  input   [5:0] apb_PADDR,
  input         apb_PSEL,
  input         apb_PENABLE,
  output        apb_PREADY,
  input         apb_PWRITE,
  input  [31:0] apb_PWDATA,
  output [31:0] apb_PRDATA,

  output reg        tl_bus_a_valid,
  input             tl_bus_a_ready,
  output     [2:0]  tl_bus_a_payload_opcode,
  output     [2:0]  tl_bus_a_payload_param,
  output reg [1:0]  tl_bus_a_payload_source,
  output reg [ADDRESS_WIDTH-1:0] tl_bus_a_payload_address,
  output     [2:0]  tl_bus_a_payload_size,
  input             tl_bus_d_valid,
  output            tl_bus_d_ready,
  input      [2:0]  tl_bus_d_payload_opcode,
  input      [2:0]  tl_bus_d_payload_param,
  input      [1:0]  tl_bus_d_payload_source,
  input      [2:0]  tl_bus_d_payload_size,
  input             tl_bus_d_payload_denied,
  input      [63:0] tl_bus_d_payload_data,
  input             tl_bus_d_payload_corrupt
);

  reg [5:0] hDrawStartO;
  reg [11:0] hDrawEnd, hDrawEndO;
  reg [11:0] hSyncStart, hSyncStartO;
  reg [11:0] hSyncEnd, hSyncEndO;
  reg [11:0] hCharInit;
  reg [11:0] hLast;
  reg hOddMode;

  reg [10:0] vDrawEnd;
  reg [10:0] vSyncStart;
  reg [10:0] vSyncEnd;
  reg [10:0] vLast;

  reg show_text;
  reg show_graphic;
  reg use_graphic_alpha;
  reg hSyncInv, vSyncInv;
  reg [4:0] hOffset, hOffsetNext;
  reg [3:0] font_height;
  localparam font_width = 3'd7; // 8 pixels
  reg [31:6] text_addr, text_addr_next;
  reg [31:6] graphic_addr, graphic_addr_next;
  reg [3:0] vTextOffset;
  reg [7:0] hTextOffset;
  reg [31:0] frame_number;
  reg odd_frame, odd_frame_buf;

  reg [10:0] charmap_index;

  // CHARMAP_SIZE = 512: symbols with codes 8-127 (ASCII)
  // CHARMAP_SIZE = 1024: symbols with codes 8-255
  // CHARMAP_SIZE = 2048: symbols with codes 8-255, two fonts
  localparam CHARMAP_SIZE = 2048;

  reg [31:0] charmap [CHARMAP_SIZE-1:0];  // 8 x 16x512 blocks
  reg [63:0] text_line [255:0];           // 4 x 16x512 blocks
  reg [63:0] graphic_line [511:0];        // 4 x 16x512 blocks

  localparam PIXEL_DELAY = 2'd3;

  // *** APB interface

  reg [3:0] apb_reg;

  always @(posedge clk) begin
    apb_reg <= apb_PADDR[5:2];
    if (reset) begin
      show_text <= 0;
      show_graphic <= 0;
      use_graphic_alpha <= 0;
      vTextOffset <= 0;
      hTextOffset <= 0;
      frame_number <= 0;
    end else begin
      odd_frame_buf <= odd_frame;
      if (frame_number[0] != odd_frame) frame_number <= frame_number + 1'b1;
      if (apb_PSEL & apb_PENABLE & apb_PWRITE) begin
        case (apb_reg)
          4'h0: {hSyncInv, vSyncInv} <= apb_PWDATA[31:30];
          4'h1: begin hDrawEnd   <= apb_PWDATA[11:0]; hOddMode <= |apb_PWDATA[5:0]; end
          4'h2: hSyncStart <= apb_PWDATA[11:0];
          4'h3: hSyncEnd   <= apb_PWDATA[11:0];
          4'h4: hLast      <= apb_PWDATA[11:0] - 1'd1;
          4'h5: vDrawEnd   <= apb_PWDATA[10:0];
          4'h6: vSyncStart <= apb_PWDATA[10:0];
          4'h7: vSyncEnd   <= apb_PWDATA[10:0];
          4'h8: vLast      <= apb_PWDATA[10:0] - 1'd1;
          4'h9: {font_height, use_graphic_alpha, show_graphic, show_text} <= {apb_PWDATA[7:4], apb_PWDATA[2:0]};
          4'hA: charmap_index <= apb_PWDATA[10:0];
          4'hB: charmap[charmap_index] <= apb_PWDATA;
          4'hC: text_addr_next <= apb_PWDATA[31:6];
          4'hD: {graphic_addr_next, hOffsetNext} <= apb_PWDATA[31:1];
          4'hE: {vTextOffset, hTextOffset} <= apb_PWDATA[11:0];
          default:;
        endcase
      end
    end
  end

  assign apb_PREADY = 1'b1;
  assign apb_PRDATA = apb_reg == 4'h1 ? {20'b0, hDrawEnd} :
                      apb_reg == 4'h5 ? {21'b0, vDrawEnd} :
                      apb_reg == 4'h9 ? {24'b0, font_height, 1'b0, use_graphic_alpha, show_graphic, show_text} :
                      apb_reg == 4'hC ? {text_addr_next, 6'd0} :
                      apb_reg == 4'hD ? {graphic_addr_next, hOffsetNext, 1'd0} :
                      apb_reg == 4'hE ? {20'b0, vTextOffset, hTextOffset} :
                      apb_reg == 4'hF ? frame_number :
                                        32'b0;

  // *** Counters

  reg [11:0] hCounter = 0;
  reg [10:0] vCounter = 0;
  reg  [7:0] hCharCounter;
  reg  [7:0] vCharCounter = 0;
  reg  [2:0] char_px;
  reg  [3:0] char_py = 0;
  reg  [3:0] text_read_steps = 1'd1;

  reg hDraw = 0;
  reg vDraw = 0;
  wire DrawArea = hDraw & vDraw;
  assign data_enable = DrawArea;

  reg [2:0] pixel_group_request_counter = 0;
  reg [2:0] pixel_group_done_counter = 0;
  reg pixel_new_line_parity = 0;
  reg pixel_new_line_done_parity = 0;
  reg text_line_request_parity = 0;
  reg text_line_done_parity = 0;
  reg text_load = 1;
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

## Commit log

2025-02-15 Add initial version of hardware/board_2a
    [conf.kicad_sch, dvi.kicad_sch, endeavour2.kicad_pcb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]
2025-02-16 PCB update
    [endeavour2.kicad_pcb]
2025-02-16 Update hardware/board_2a
    [endeavour2.kicad_pcb, endeavour2.kicad_sch, peripherals.kicad_sch]
2025-05-04 Production files in ../hardware/board_2a
    [bom.csv, designators.csv, endeavour2_upd.kicad_pcb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]
2025-05-04 Add audio controller; add frequency counters; update ddr3_adapter according to on-device debugging results
2025-05-04 rtl: add I2C controller, connect ESP32 UART; bios: add "date" command
2025-05-04 Fixed sdcard read/write functions (controller returns big endian instead of little endian); added EXT2 support, loading BMP wallpaper; added support of 4-color characters.
    [video_controller.v]
2025-05-04 Load BIOS image from SPI flash on boot.
2025-05-04 Remove kicad_prl from repo
2025-05-04 linux drivers; textwm2
    [textwm2.cfg]
2025-05-04 Fix bug in video controller - first text line was loaded from RAM only partially
    [video_controller.v]
2025-05-04 Update textwm
    [textwm2.cfg]
2025-05-04 Update textwm; show logo on ^[?314e
    [textwm2.cfg]
2025-05-13 Add RTC driver
2025-06-04 Add audio driver
2025-06-11 Framebuffer driver
2025-06-17 Remove debug message in display driver
2025-12-26 A few utils for experimenting with onboard ESP32 module
2025-12-26 Case for endeavour2a board; Freecad model for 3d printing
    [case_bottom.stl, case_top.stl]
2026-01-23 Add hardware/board_2b
    [bom.csv, case_bottom.stl, case_middle.stl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]
2026-01-23 Add spi controller with fifo; connect esp32
2026-01-23 Rename hardware/extension -> ext_2a_to_2b
    [bom.csv, designators.csv, ext.kicad_pcb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]
2026-01-23 Update linux drivers
2026-01-28 Add DMA controller; update VexiiRiscv; CPU frequency decreased 220 MHz -> 200 MHz
2026-02-05 Update hardware/board_2b
    [bom.csv, conf.kicad_sch, designators.csv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]
2026-02-06 Set allowed dma buffer range from [128, 8192] to [0, 8192-128]
2026-02-07 gpio controller ; spi controller for e2417 display ; bugfixes
2026-02-08 Check DTB crc32 when boot linux via UART
2026-02-25 Fix bug in videcontroller - wrong pixel on right side of the screen in resolution 800x600
    [video_controller.v]
2026-02-25 Fix gpio pin numbers in defs.h
2026-02-25 Add DMA bindings to display driver
2026-02-25 Add DMA interrupt in DTS
2026-02-26 Add MIXRGB instruction to DMA controller
2026-02-26 Remove deprecated gpio driver; comment some debug output in uart driver.
2026-03-04 Add X11 fbdev driver which uses endeavour DMA to move windows
2026-03-04 Comment some debug output in display driver
2026-03-04 Remove hardware/ext_2a_to_2b (it was for testing, not needed anymore)
    [bom.csv, designators.csv, ext.kicad_pcb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]
2026-03-09 Update BIOS. Add EDID parsing, battery status, E-Ink display support.
2026-03-13 Update board_2b case 3d model
    [case_bottom.stl, case_middle.stl, case_middle_f.stl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]
2026-03-13 Update fifo_spi driver; comment debug prints in uart driver
2026-03-13 Add patch for esp-hosted-ng kernel module. Update kernel and buildroot configs. Now ESP32 works as WiFi adapter in endeavour2.
2026-09-28 Fix potential race condition in drivers/display.c
